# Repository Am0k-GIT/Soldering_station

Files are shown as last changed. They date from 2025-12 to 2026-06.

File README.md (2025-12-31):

<p align="center">
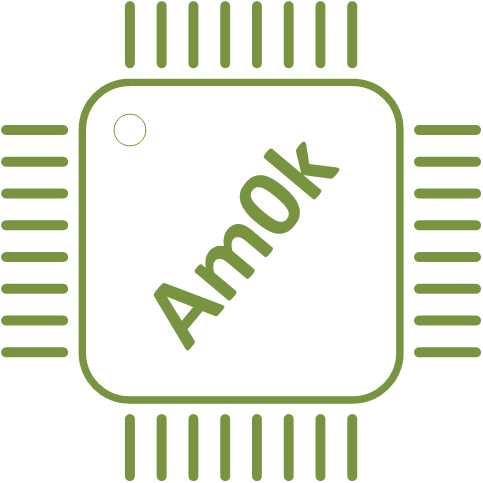
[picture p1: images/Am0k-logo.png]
  
</p>

<h1 align="center">Soldering Station</h1>

Паяльная станция основана на микроконтроллере от фирмы  STMicroelectronics STM32F401RCT6 и создана для одновременной работы с паяльником и термофеном. 
Она скомпонована на 2 печатных платах размером 100x70 мм. На первой (основной) печатной плате расположены: схема формирования вторичных напряжений питания, 
микроконтроллер и его обвязка, схема формирования входных сигналов АЦП на базе rail-to-rail ОУ, ключи управления нагрузкой (нагреватель паяльника, турбина фена, 
внешний вентилятор-дымоуловитель), кнопки управления, энкодеры, цветной LCD экран 1.77’’, разъемы для подключения. На второй печатной плате расположены элементы, 
касающиеся цепи питания 220В: реле включения блока питания паяльной станции, реле подключения ручки фена, симисторный драйвер управления нагревателем фена.

## Особенности.
<p align="center">
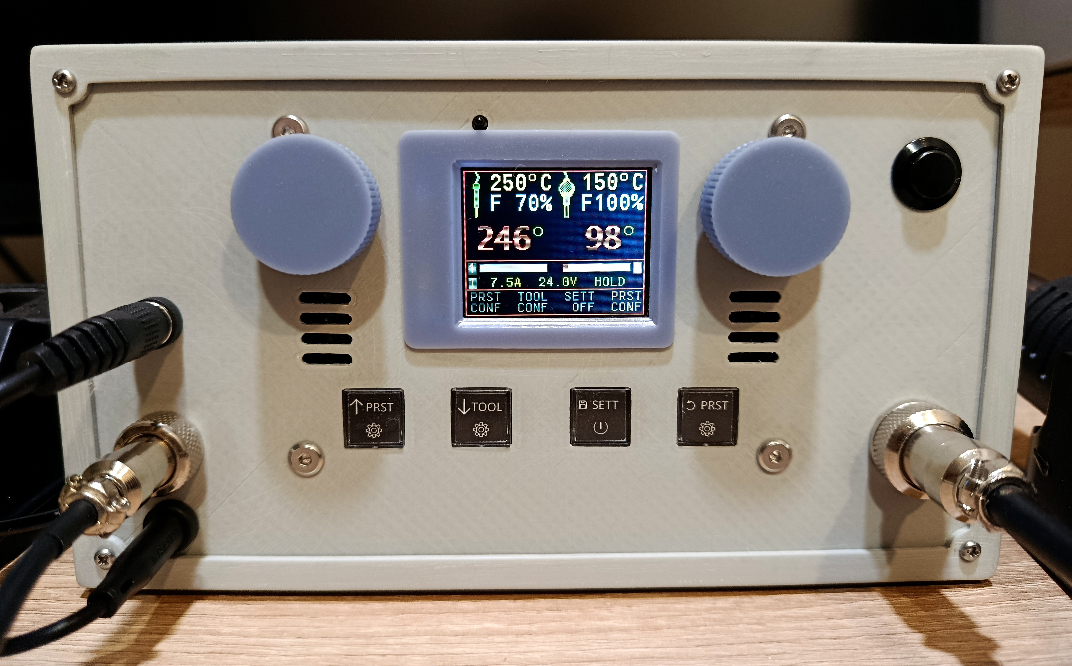
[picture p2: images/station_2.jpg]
  
</p>

Основные особенности:
- Напряжение питания 12-24 вольт от внешнего источника питания
- Одновременное подключение паяльника и термофена
- Возможность работы с жалами-картриджами с последовательным подключением нагревателя и термопары (как T12) или с общей землей нагревателя и термопары (как C245)
- PID управление мощностями нагревателей паяльника и термофена
- Широкий спектр доступных настроек для тюнинга станции под свои нужды

## BOM и производство.

Оригинальные печатные платы были произведены PCBWave. Для самостоятельного изготовления или заказа вы можете воспользоваться
GERBER-файлами и BOM-листом, приложенными в репозитории.

## Обратная связь.

Буду рад любой обратной связи относительно этого проекта, а так же отвечу на вопросы.
Почтовый адрес `b1gb0ss@mail.ru`.
Так же буду крайне благодарен в случае помощи с качественным переводом информации, размещенной в данном репозитории.

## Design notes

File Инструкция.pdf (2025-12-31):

## двухканальная паяльная станция от Am0k

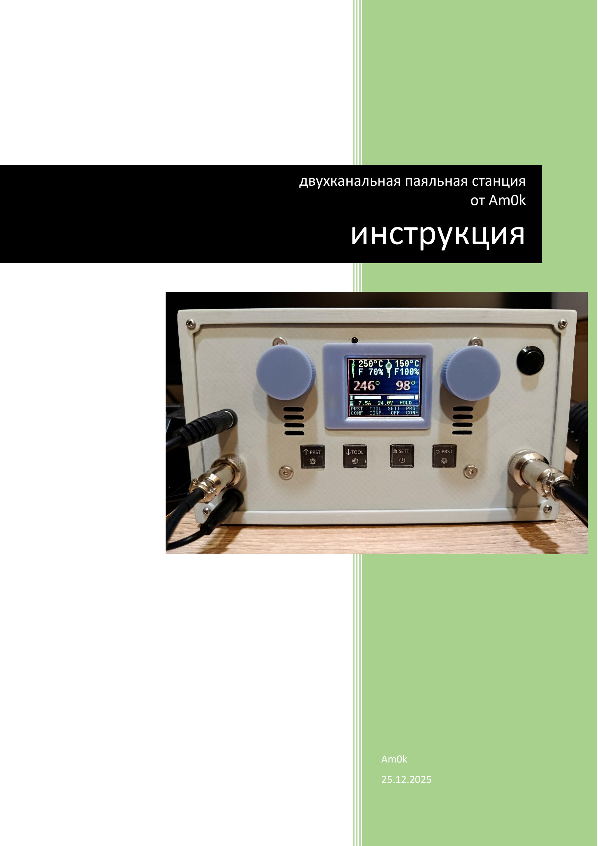
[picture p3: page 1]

Am0k

25.12.2025

# инструкция

## Оглавление

Общие технические характеристики.

Паяльная станция Helga основана на микроконтроллере от фирмы STMicroelectronics STM32F401RCT6 и создана для одновременной работы с паяльником и термофеном. Она скомпонована на 2 печатных платах размером 100x70 мм. На первой (основной) печатной плате расположены: схема формирования вторичных напряжений питания, микроконтроллер и его обвязка, схема формирования входных сигналов АЦП на базе rail-to-rail ОУ, ключи управления нагрузкой (нагреватель паяльника, турбина фена, внешний вентилятор-дымоуловитель), кнопки управления, энкодеры, цветной LCD экран 1.77’’, разъемы для подключения. На второй печатной плате расположены элементы, касающиеся цепи питания 220В: реле включения блока питания паяльной станции, реле подключения ручки фена, симисторный драйвер управления нагревателем фена.

Основные особенности:

- Напряжение питания 12-24 вольт от внешнего источника питания
- Одновременное подключение паяльника и термофена
- Возможность работы с жалами-картриджами с последовательным подключением нагревателя и термопары (как T12) или с общей землей нагревателя и термопары (как C245)
- PID управление мощностями нагревателей паяльника и термофена
- Широкий спектр доступных настроек для тюнинга станции под свои нужды

Подключение станции.

Для подключения станции потребуется блок питания напряжением 12-24 вольта, обеспечивающий мощность для выбранного типа жал, а также дополнительные 100 мА на нужды станции и ток, необходимый для внутреннего кулера обдува, турбины термофена, вентилятора-дымоуловителя. По умолчанию в станции установлен предохранитель 10А типоразмера 1808, который может быть заменен при необходимости.

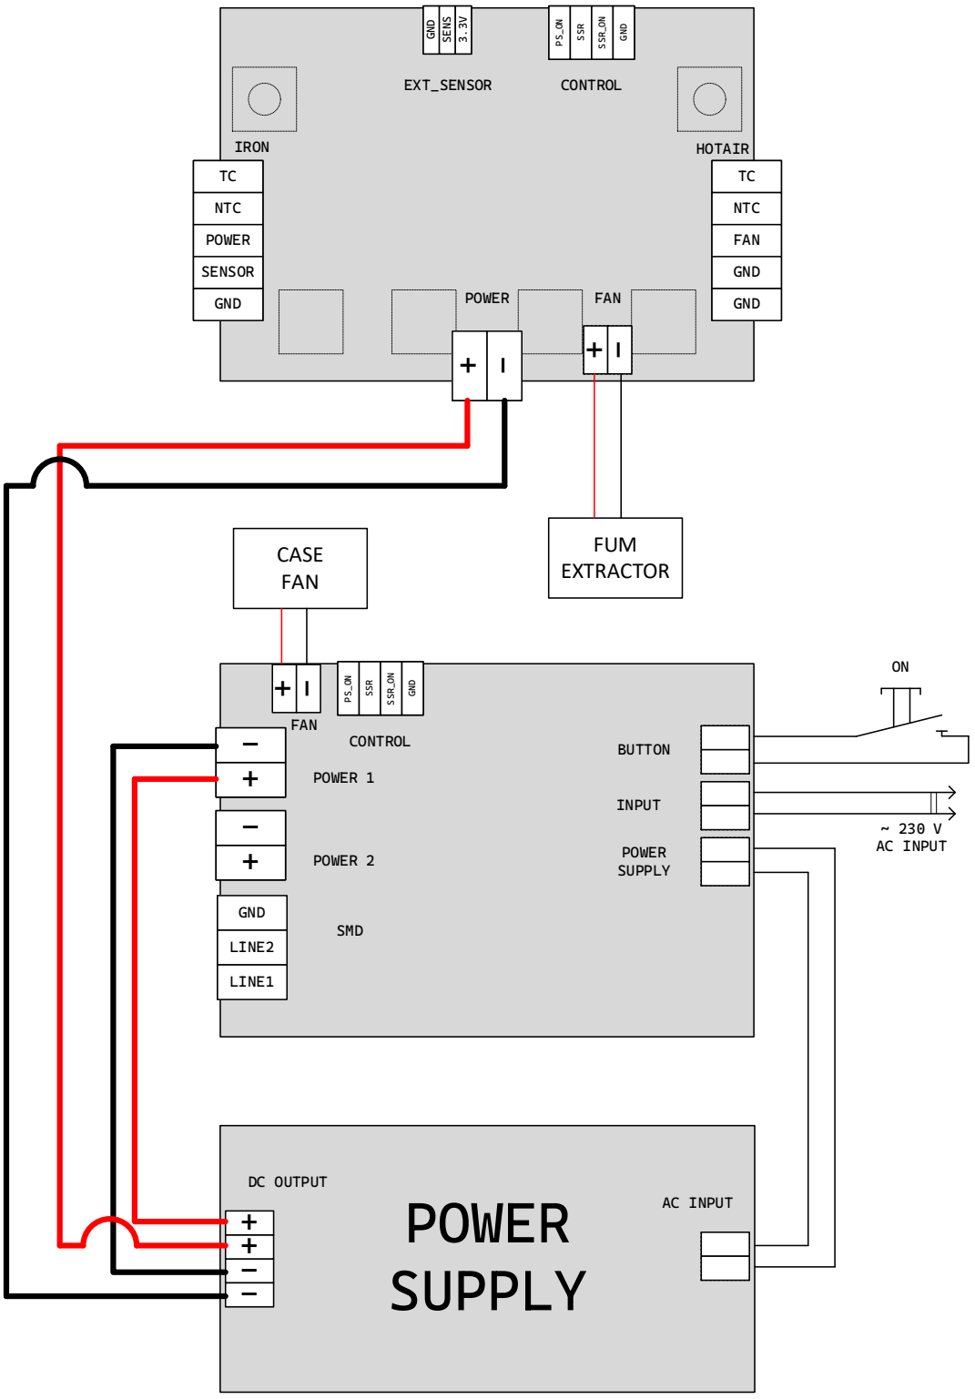
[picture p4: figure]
NTC; POWER; SENSOR; GND; FAN; - GND SENS 3.3V PS_ON SSR SSR_ON GND; EXT_SENSOR; CONTROL; IRON; HOTAIR PS_ON; SSR; SSR_ON; BUTTON; POWER 1; POWER 2; LINE2; LINE1; SMD; INPUT; POWER SUPPLY; POWER SUPPLY ⁻ -; AC INPUT; DC OUTPUT; FUM EXTRACTOR; CASE FAN; ~ 230 V AC INPUT

При отсутствии возможности подключения к блоку питания одновременно двух потребителей, на дополнительной плате предусмотрен разъем POWER 2, по сути являющийся дублирующим для POWER 1. В таком случае к блоку питания подключается только дополнительная плата, а основная подключается к разъему POWER 2.

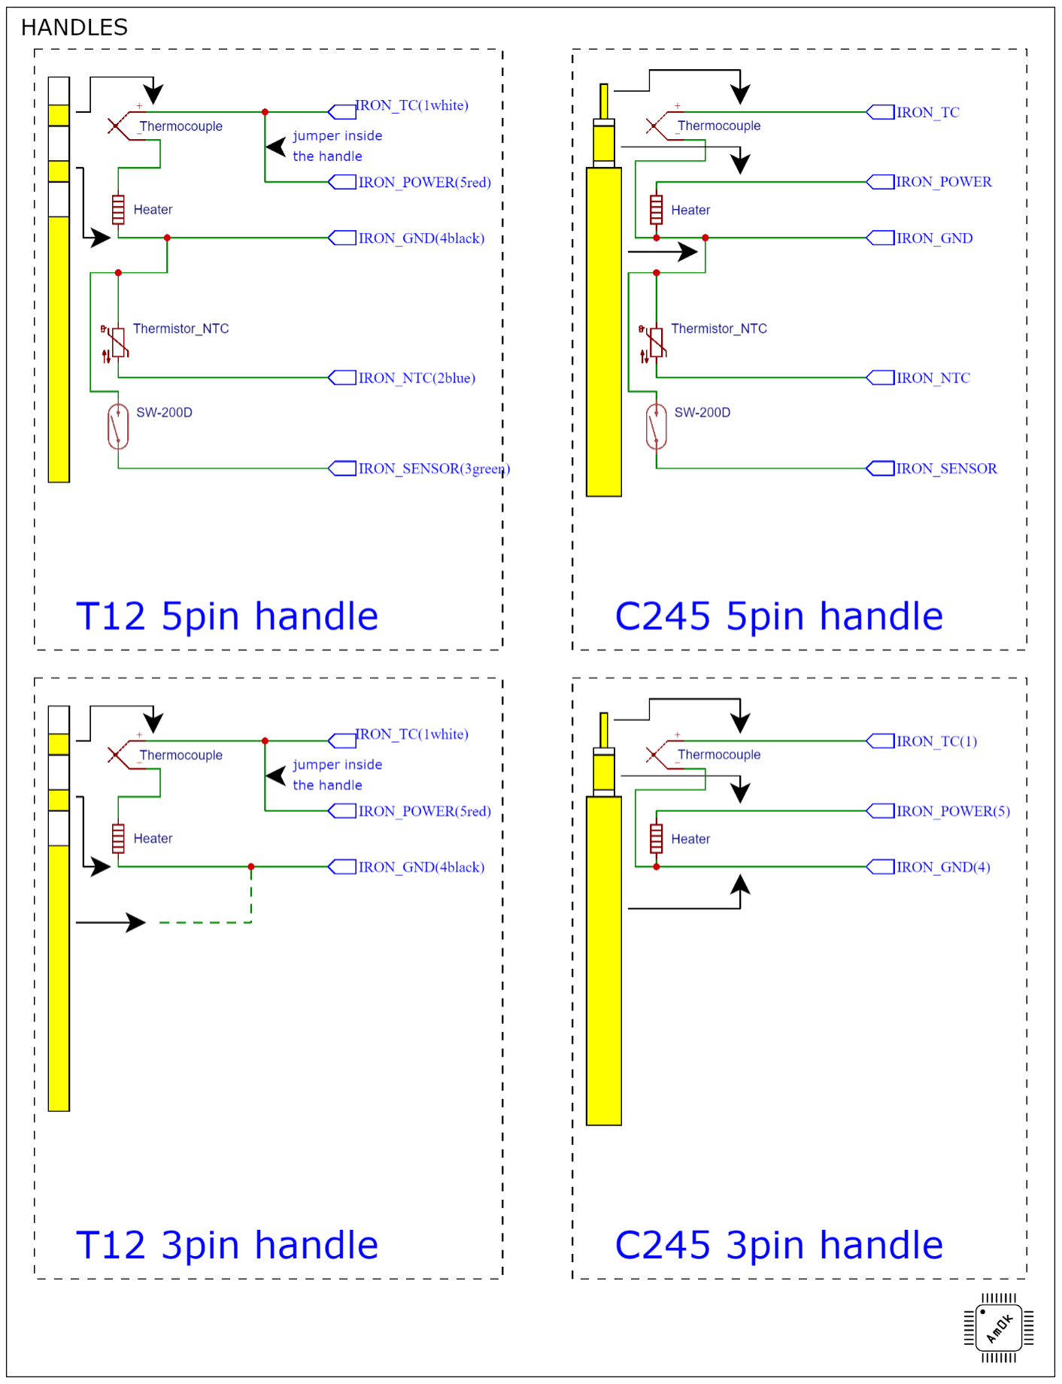
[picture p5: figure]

Рукоятки паяльника могут быть подключены по 3-ех, 4-ех или 5-ти проводной схеме, в зависимости от наличия внутреннего NTC резистора в рукоятке и датчика вибрации.

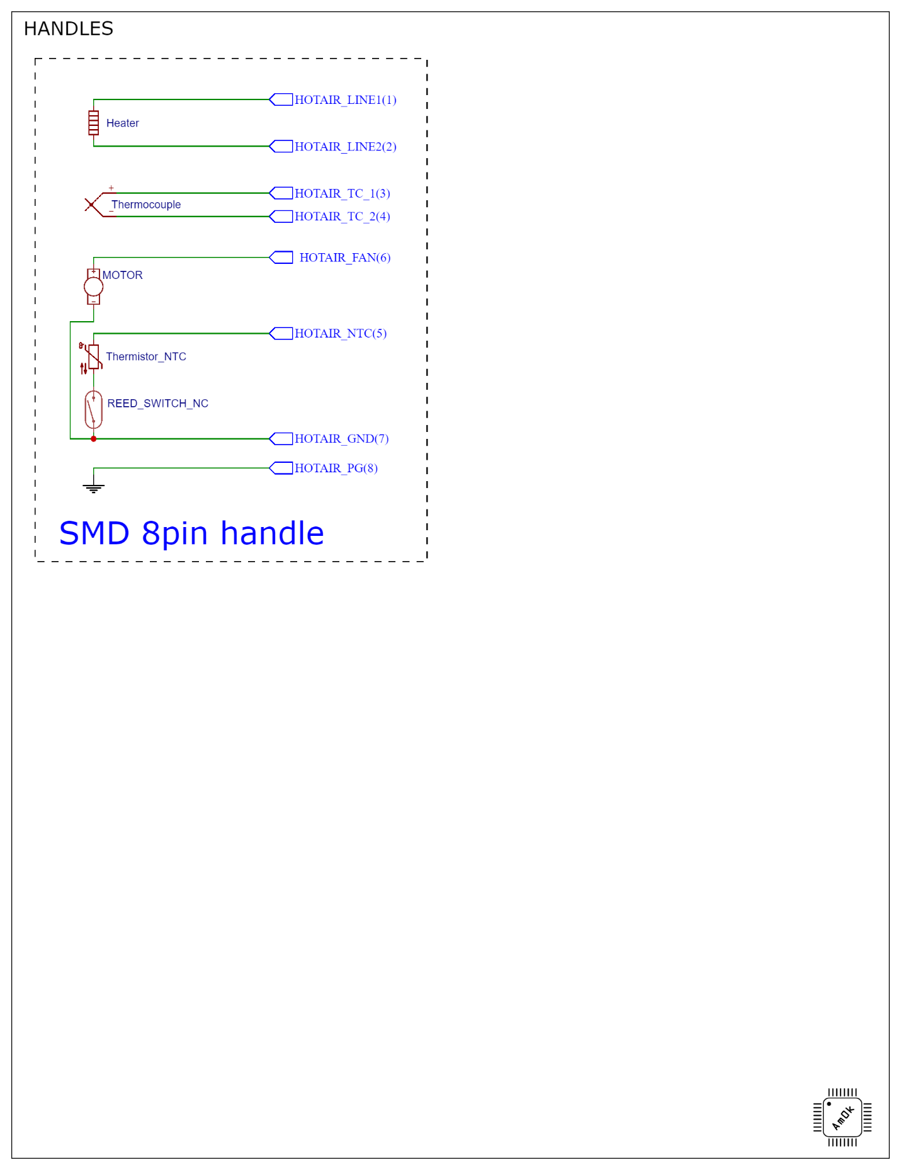
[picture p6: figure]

Рукоятка термофена подключается по 8 проводной схеме. Сигналы LINE1, LINE2 и PG берутся с разъема дополнительной печатной платы. Отрицательный вывод термопары подключается на один из выводов GND разъема HOTAIR основной печатной платы.

Так же между печатными платами устанавливается шлейф для управления дополнительной печатной платой (разъемы CONTROL, одноименные сигналы соединяются друг с другом).

Подключение подставки с детектированием наличия инструмента.

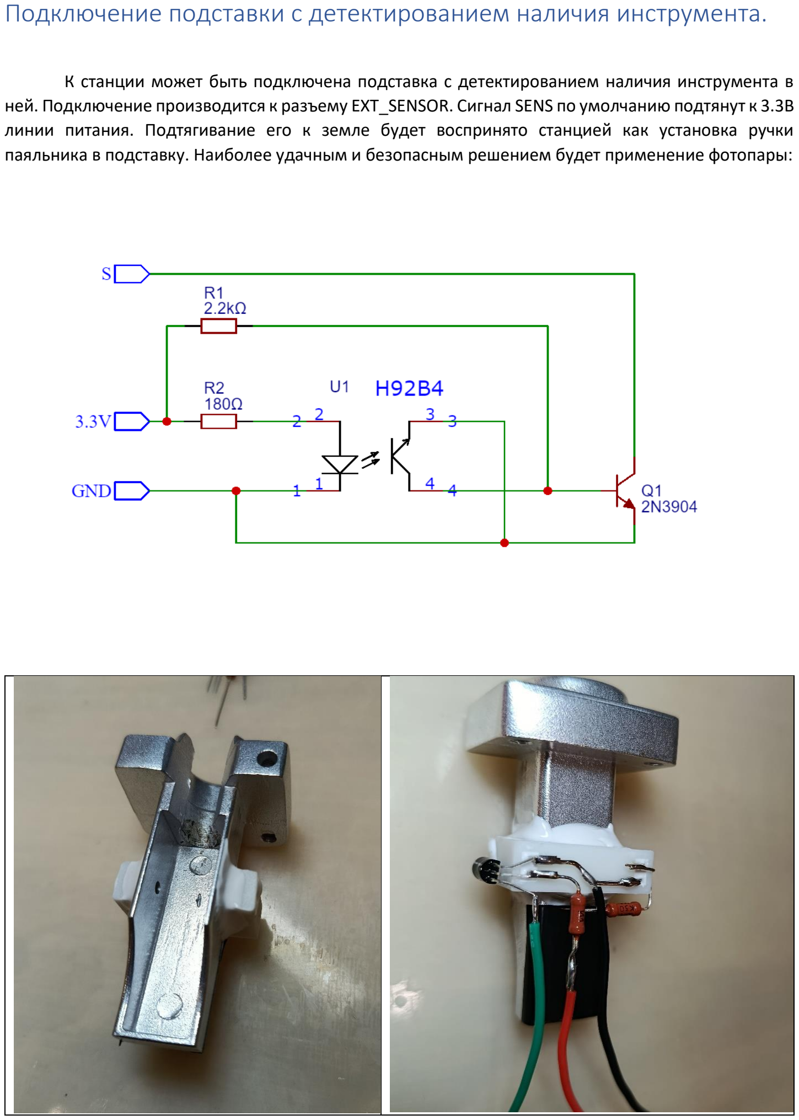
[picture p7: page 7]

К станции может быть подключена подставка с детектированием наличия инструмента в ней. Подключение производится к разъему EXT_SENSOR. Сигнал SENS по умолчанию подтянут к 3.3В линии питания. Подтягивание его к земле будет воспринято станцией как установка ручки паяльника в подставку. Наиболее удачным и безопасным решением будет применение фотопары:

Алгоритм работы.

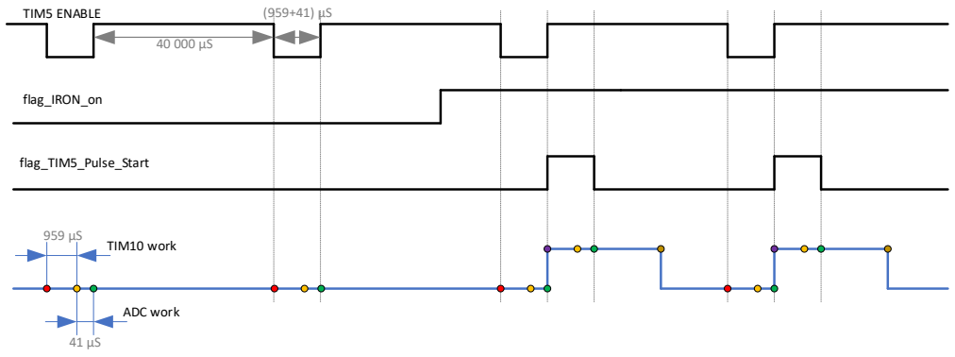
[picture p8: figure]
TIM5 ENABLE; flag_IRON_on; TIM10 work; ADC work; flag_TIM5_Pulse_Start

Алгоритм работы станции рассчитан на работу как с жалами, имеющими последовательное соединение термопары и нагревателя, так и с трех-контактными жалами с общим минусом для термопары и нагревателя. Частота ШИМ сигнала составляет 25 Гц. По завершению каждого периода ШИМ осуществляется задержка длительностью 959 мкС., после которой начинает свою работу АЦП. По завершению работы АЦП вновь следует запуск импульса ШИМ и одновременно сигнала задержки для нового измерения, на этот раз уже во время непосредственного нагрева (в случае его включения) измеряется ток, текущий через нагреватель жала. При завершении положительного импульса ШИМ, если АЦП еще не завершил работу, устанавливается флаг, указывающий на слишком короткий импульс для достоверного измерения тока. Подробные блок-схемы работы ПО в части, касающейся работы АЦП и ШИМ, приведены в справочной информации.

Меню и управление станцией.

Меню загрузки.

# RST EXIT

# LOADING SETTINGS:

IRON SETT. | - OK
HOTAIR SETT. | - OK
HW SETT. | - OK
IRON TOOLS | - OK
HOTAIR TOOLS | - OK
IRON PRES. | - OK
HOTAIR PRES. | - OK
VERSION: | 251103

При включении станции на экране появится меню загрузки. В нем будут отображены параметры успешности загрузки всех сохраняемых в EEPROM настроек. В случае успешной загрузки напротив блока настроек появится надпись OK, в случае, если настроек нет (они ни разу не были сохранены в EEPROM), будут загружены настройки по-умолчанию для данного блока, и появится надпись FAIL. Внизу экрана будет отображена версия прошивки. Доступные кнопки: RST для полной очистки EEPROM и установки настроек по-умолчанию, EXIT для мгновенного выхода из меню без ожидания автоматической загрузки следующего меню.

Основное меню.
250°C | 150°C
F100% | F 80%
PRST | TOOL | SETT | PRST
CONF | CONF | OFF | CONF
1 | | 1
2 | 8.2A 24.1V HOLD
249° | 138°

Находясь в основном меню, экран разделен на несколько зон в соответствии с их назначением.

В верхней левой части экрана отображаются параметры, касающиеся паяльника: установленная температура, установленная скорость работы вентилятора-дымоуловителя, реальная температура. Отображаемое значение реальной температуры меняет цвет в зависимости от того, включен ли нагрев (красный при включении, зеленый при отключении нагрева).

В верхней правой части экрана отображаются параметры, касающиеся термофена: установленная температура, установленная скорость работы турбины, реальная температура. Отображаемое значение реальной температуры меняет цвет в зависимости от того, включен ли нагрев (красный при включении, зеленый при отключении нагрева).

В средней части экрана отображаются: индикатор подаваемой на нагреватели паяльника (слева) и термофена (справа) мощности. Также отображаются номер установленного пресета и установленного инструмента для паяльника слева, и установленного пресета для термофена справа. Ниже находится справочная информация: потребляемый нагревателем жала паяльника ток или его состояние (HOLD при удержании температуры сна, ----- при отключении инструмента из за неиспользования), напряжение блока питания, состояние термофена.

В нижней части расположена подсказка по управлению станции с помощью кнопок, где верхний ряд – короткое нажатие соответствующей кнопки, нижний ряд – длинное нажатие, список приведен слева направо:

PRST – переключение пресетов для паяльника

CONF – меню настройки пресетов паяльника

TOOL – переключение предварительно откалиброванных инструментов (жал) для паяльника

CONF – меню настройки инструментов

SETT – меню настроек станции

OFF – отключение станции

PRST – переключение пресетов для термофена

CONF – меню настройки пресетов термофена

Левый энкодер меняет параметры, касающиеся пальника: установленную температуру и обдув вентилятора-дымоуловителя. Короткое нажатие энкодера переключается между параметрами (температура или нагрев), длинное включает и выключает нагрев.

Правый энкодер меняет параметры, касающиеся термофена: установленную температуру и скорость турбины. Короткое нажатие энкодера переключается между параметрами (температура или нагрев), длинное включает и выключает нагрев.

Меню настроек.

В меню настроек вы можете настроить основные параметры станции. Кнопки BACK и NEXT перемещают курсор > выбора параметра. Кнопка SAVE сохраняет блок настроек в EEPROM, кнопка EXIT закрывает меню и переводит экран в режим отображения основного меню.

Вращая правый энкодер при установленном на название страницы настроек курсоре вы можете переключать страницы настроек между HOTAIR SETTINGS, IRON SETTINGS, HW SETTINGS. Если же курсор установлен на одном из пунктов настроек, то его вращение приведет к изменению значения.

BACK | NEXT | SAVE | EXIT

# > HOTAIR SETTINGS:

MIN TEMP: | 120°C
MAX TEMP: | 450°C
STEP TEMP: | 10°C
MIN FLOW: | 40 %
MAX FLOW: | 100 %
STEP FLOW: | 10 %
TOOL NTC: | MF52
TOOL SENSOR: | Y
SLEEP TIMER: | 60 S

Доступные в меню HOTAIR SETTINGS настройки:

MIN TEMP – минимальная температура, которую можно установить

MAX TEMP – максимальная температура, которую можно установить

STEP TEMP – шаг изменения температуры

MIN FLOW – минимальный поток воздуха, который можно установить

MAX FLOW - максимальный поток воздуха, который можно установить

STEP FLOW – шаг изменения потока воздуха

TOOL NTC – выбор NTC, установленного в рукоятке. N означает отсутствие NTC, в таком случае для подсчета температуры холодного спая будет использован NTC, установленный в станции

TOOL SENSOR – установлен ли в ручке сенсор

SLEEP TIMER – время, через которое термофен перейдет в режим HOLD, будучи установленным в подставку

BACK | NEXT | SAVE | EXIT
> | IRON SETTINGS:
MIN TEMP: | 120°C
MAX TEMP: | 450°C
STEP TEMP: | 10°C
MIN FLOW: | 40 %
MAX FLOW: | 100 %
STEP FLOW: | 10 %
TOOL NTC: | N
TOOL SENSOR: | N
SLEEP TIMER: | 60 S

Настройки подменю IRON SETTINGS аналогичны. Если TOOL SENSOR установлен в N (в ручке нет сенсора), то будет использован внешний сенсор (активная подставка).

BACK | NEXT | SAVE | EXIT
> | HW SETTINGS:
INT NTC: | MF52
0 CURRENT: | 2290
K CURRENT: | 100
K VOLTAGE: | 100
K INT NTC: | 100
K IRON NTC: | 100
K HOTAIR NTC: | 100
TIME OFF: | 1200 S
OVERCURRENT: | 8 A

Страница настроек HW SETTINGS содержит следующие пункты:

INT NTC – выбор встроенного в плату станции NTC

0 CURRENT – показания АЦП для нулевого тока ACS712-20A

K CURRENT – коэффициент коррекции для измерения тока жала

K VOLTAGE – коэффициент коррекции для измерения напряжения блока питания

K INT NTC – коэффициент коррекции для измерения температуры встроенным NTC

K IRON NTC – коэффициент коррекции для измерения температуры NTC, встроенным в рукоятку паяльника

K HOTAIR NTC – коэффициент коррекции для измерения температуры NTC, встроенным в рукоятку фена

TIME OFF – время перехода инструмента из режима HOLD в режим OFF

OVERCURRENT – максимальное значение тока жала паяльника. При превышении нагрев прекращается.

Меню настройки пресетов паяльника.

BACK | NEXT | SAVE | EXIT

# IRON PRESETS:

#1 | >T:250°C | F: 70%

#2 | T:270°C | F: 80%

#3 | T:320°C | F:100%

В меню настройки пресетов паяльника можно сохранить 3 различных пресета. Кнопками BACK и NEXT осуществляется навигация по меню, вращение правого энкодера меняет значение выбранного параметра.

Меню настройки пресетов термофена.

BACK | NEXT | SAVE | EXIT

# HOTAIR PRESETS:

#1 | >T:150°C | F:100%

#2 | T:320°C | F: 60%

#3 | T:350°C | F:100%

В меню настройки пресетов паяльника можно сохранить 3 различных пресета. Кнопками BACK и NEXT осуществляется навигация по меню, вращение правого энкодера меняет значение выбранного параметра.

Меню настройки инструментов.

BACK | NEXT | SAVE | EXIT

# > TOOL: IRON#1

P: | 200
I: | 100
D: | 200
ADC (Δ 0°C): | 90
ADC (Δ120°C): | 600
ADC (Δ240°C): | 1330
ADC (Δ360°C): | 2040
026°C Δ120°C | 612

В меню настройки инструментов навигация осуществляется стандартным способом. При выборе заголовка меню вращение правого энкодера меняется инструмент (термофен и 5 вариантов жал паяльника). Кнопки BACK и NEXT перемещают курсор выбора пункта меню вверх и вниз соответственно. Доступные пункты меню:

P – коэффициент P для PID регулятора выбранного инструмента

I - коэффициент I для PID регулятора выбранного инструмента

D - коэффициент D для PID регулятора выбранного инструмента

ADC (Δ 0°C) - ADC (Δ360°C) – показания АЦП при заданной дельте темпретаруры термопары и холодного спая.

Ниже расположены значения: температура холодного спая (зеленым), дельта температуры термопары и холодного спая (красным) и текущие показания АЦП (желтым). Под ними расположена шкала коррекции. Подробнее о функциональном назначении данной страницы настроек рассказано в главе “Калибровка инструментов”.

Калибровка инструментов.

Для калибровки инструментов перейдите в меню настройки инструментов и выберите в заголовке требуемый инструмент.

Для базовой настройки PID регулятора сначала установите коэффициенты P, I, D в ноль.

P – пропорциональная составляющая воздействия вашего регулятора. Ее значение пропорционально отклонению регулируемой величины (температуры в нашем случае) от заданного значения. Сама по себе пропорциональная составляющая не способна привести к стабилизации системы. По мере увеличения составляющей будет происходить перерегулирование в виде появление вначале незатухающих колебаний, а затем и вовсе колебаний с нарастающей амплитудой. Идеально подобранный коэффициент P позволит стабилизироваться системе в состоянии небольшого недогрева с незначительными колебаниями. Так, при выставленной температуре в 250°С, постепенным увеличением коэффициента P будет необходимо добиться выхода системы на температуру 245-249°С с незначительными колебаниями (не более 5°С). Это наиболее важный этап настройки регулятора, и он потребует нескольких итераций. Просто увеличивайте коэффициент P, возвращайтесь в главное меню и следите за изменениями в стабильности системы.

I - интегрирующая составляющая, она пропорциональна интегралу по времени от отклонения регулируемой величины. Ее основное значение – компенсация статической ошибки в виде небольшого недогрева, полученного при настройке коэффициента P. Необходимо столь же плавно увеличивать ее до тех пор, пока система не начнет стабилизироваться вокруг установленной температуры с незначительными (1-2°С) колебаниями. Слишком малое значение коэффициента I не позволит системе достигнуть заданной температуры. Однако чрезмерное значение коэффициента приведет к увеличению инертности системы, что подходит для термофена, но не для жала паяльника.

D - дифференцирующая составляющая, она пропорциональна темпу изменения отклонения регулируемой величины и предназначена для противодействия отклонениям от целевого значения. Именно эта составляющая будет “сопротивляться” резкому изменению температуры. Однако, это будет выражаться не только в значительном увеличении подаваемой мощности во время просадки температуры при касании крупного медного полигона жалом паяльника, но и при резком возвращении температуры в момент прекращения значительного отбора тепла. Для точного подбора этого коэффициента потребуется практическое применение паяльника с возможно большим отбором тепла. Увеличивайте коэффициент от нуля до значения, при котором система не уходит в перерегулирование и не начинаются выбросы температуры. Для термофена этот коэффициент имеет наименьшее практическое значение.

Несмотря на то, что регулировка коэффициентов PID долгий и порой неоднозначный по выводам процесс, именно тонкий подбор коэффициентов позволит раскрыть полный потенциал инструмента.

Тарирование термопары инструмента необходимо производить после калибровки PID и получения на выходе регулятора стабильной температуры.

На полностью холодном инструменте установите ADC (Δ 0°C) равное текущим показаниям АЦП.

При переходе на пункт ADC (Δ120°C) начнется нагрев инструмента до температуры (Tntc + 120)°C. Добейтесь стабилизации температуры и начните контроль реальных значений температуры внешним измерительным прибором. Используйте легкоплавкие припои (сплав Вуда, сплав Розе) для калибровки по крайней мере этой точки тарирования. Вращая левый энкодер, вы можете увеличивать и уменьшать установленную температуру, нижняя цветная шкала соответствует вносимой вами поправке. Необходимо добиться стабильных показаний реальной температуры, соответствующих (Tntc + 120)°C, после чего вращением правого энкодера ввести установившееся значение АЦП. Если достигнуты границы возможной поправки, можно сохранить достигнутый результат, выйти из меню, и затем вернуться в него вновь. Это вновь установит поправку в 0 (середина шкалы), однако установленная температура будет уже больше соответствовать реальной за счет обновленного значения АЦП.

Повторите предыдущий пункт для пунктов ADC (Δ240°C) и ADC (Δ360°C).

При сохранении результатов, в таблицу калибровки в EEPROM так же будет записано автоматически посчитанное значение максимально измеряемой температуры при 4000 отсчетов АЦП. Этот результат будет получен аппроксимацией участка ADC (Δ240°C) - ADC (Δ360°C).

Справочная информация.

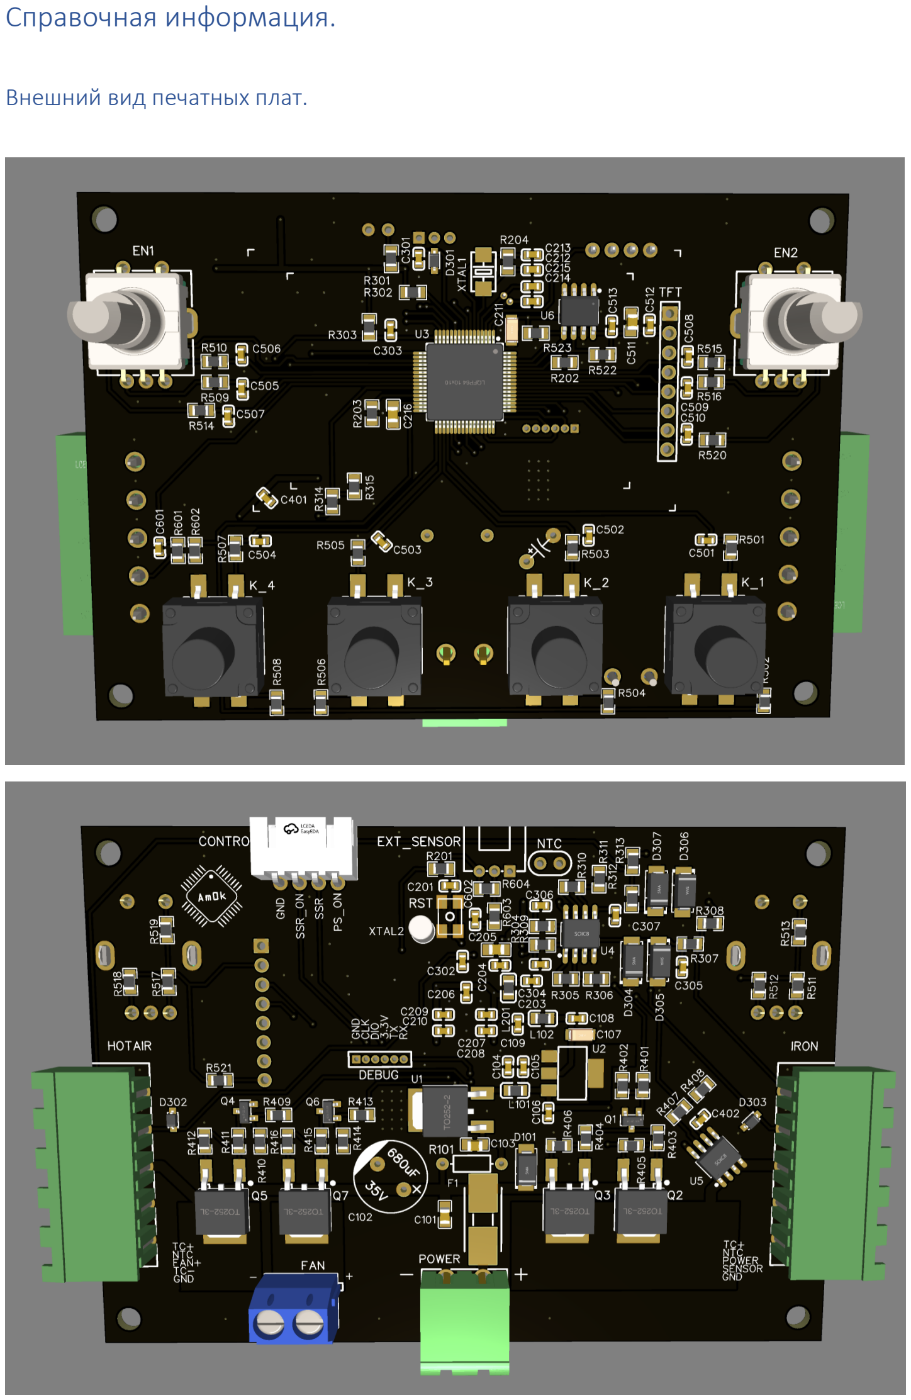
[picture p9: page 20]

Внешний вид печатных плат.

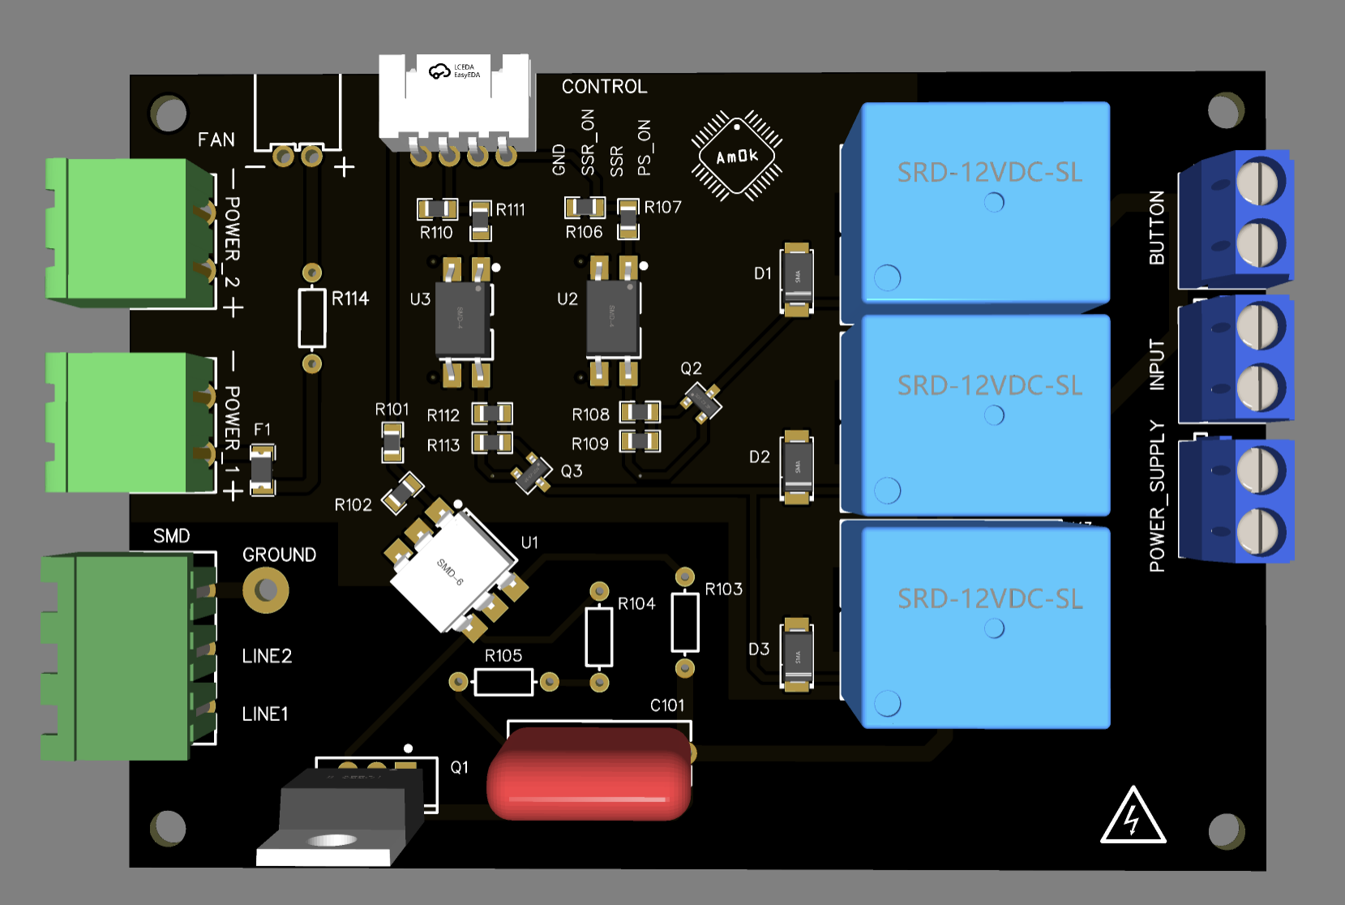
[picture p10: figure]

Размеры.

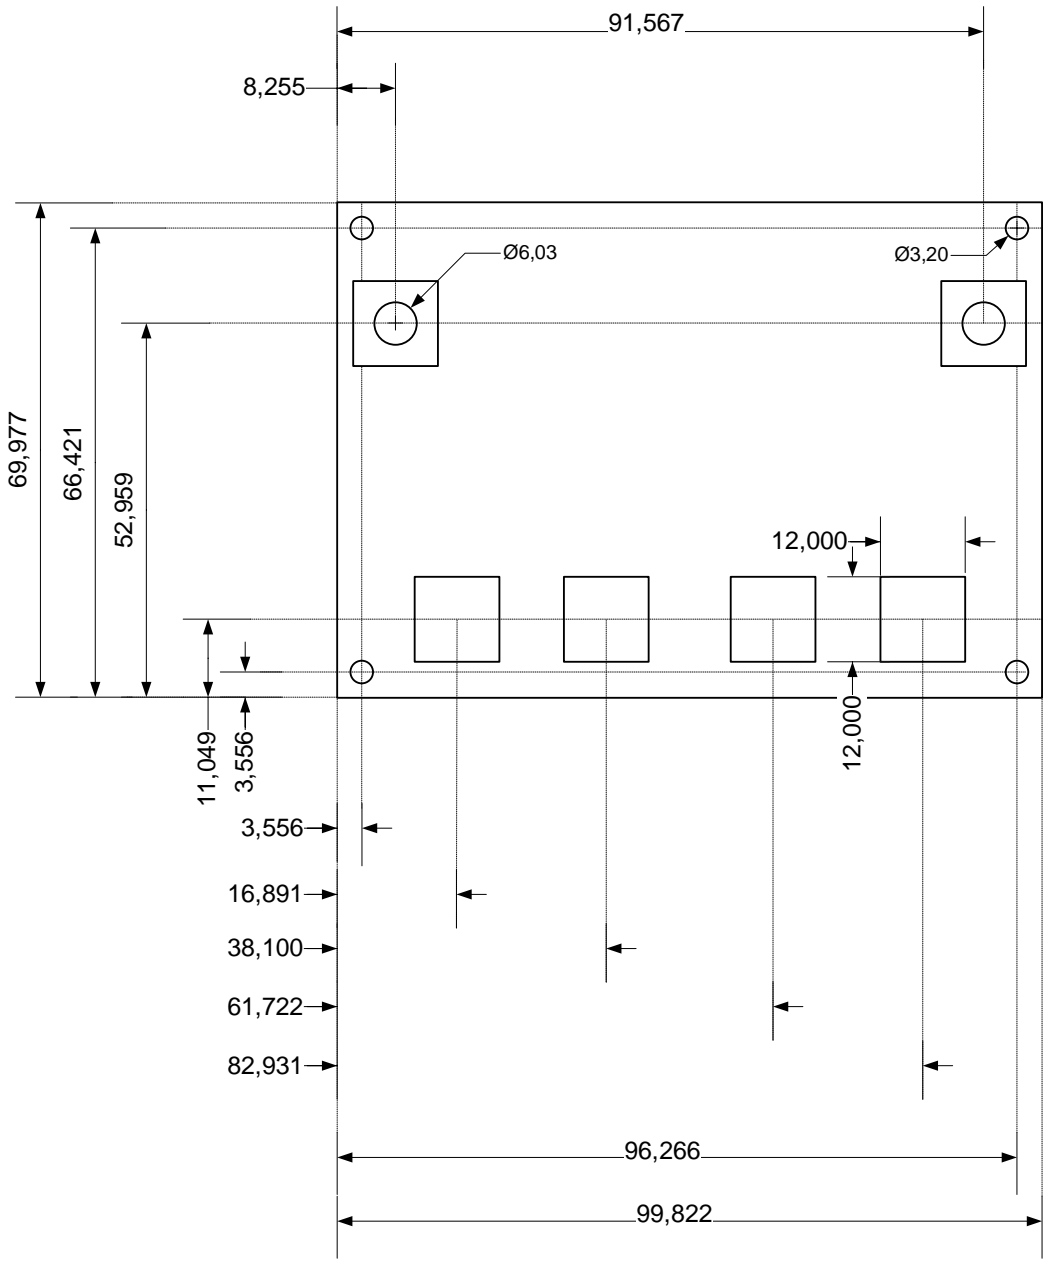
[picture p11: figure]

Алгоритм обработки нажатия кнопок.

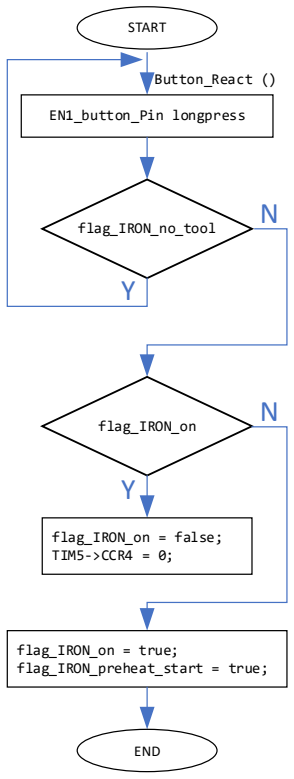
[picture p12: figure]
START; EN1_button_Pin longpress; flag_IRON_no_tool; flag_IRON_on; flag_IRON_on = false; TIM5->CCR4 = 0;; flag_IRON_on = true; flag_IRON_preheat_start = true;; END; Button_React ()

Алгоритм обработки завершения импульса ШИМ нагрева.

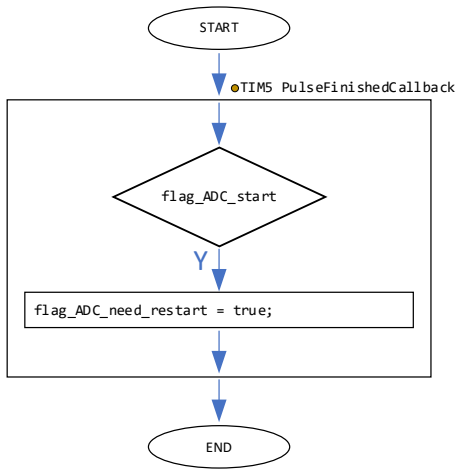
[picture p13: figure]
START; TIM5 PulseFinishedCallback; END; flag_ADC_start; flag_ADC_need_restart = true;

Алгоритм работы АЦП и ШИМ.

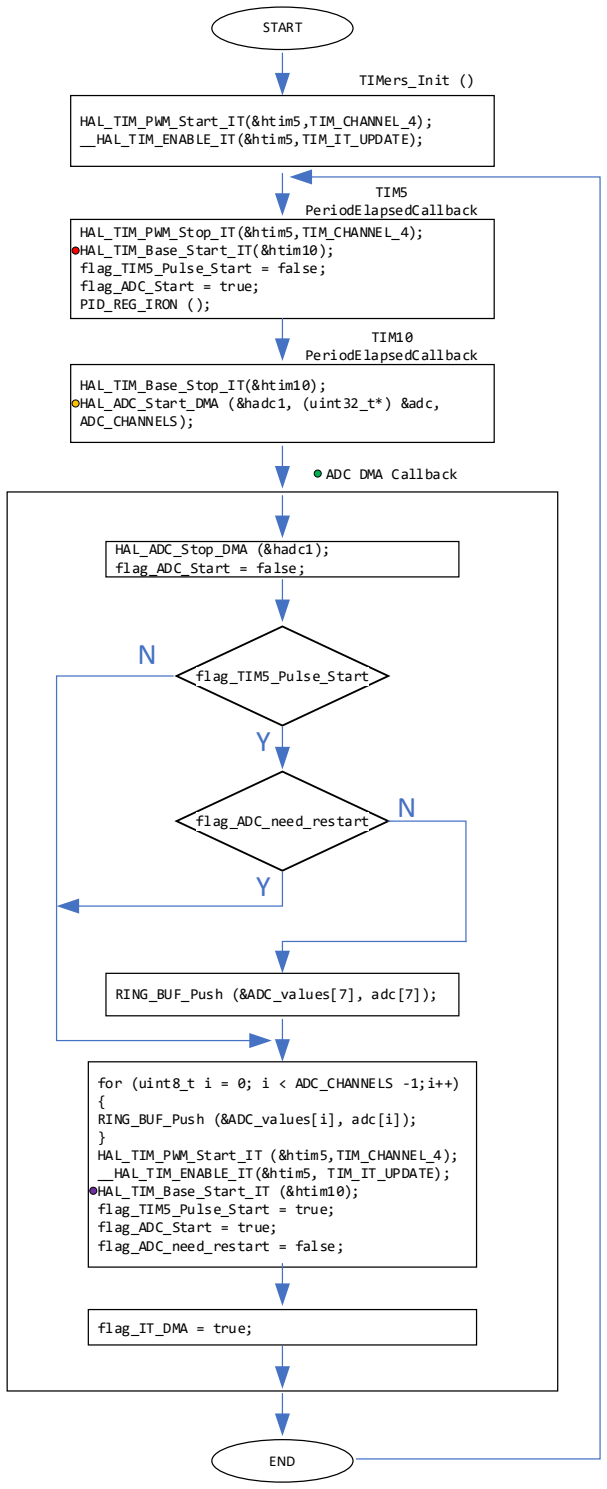
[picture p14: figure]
START; HAL_TIM_PWM_Start_IT(&htim5,TIM_CHANNEL_4); __HAL_TIM_ENABLE_IT(&htim5,TIM_IT_UPDATE);; TIMers_Init (); HAL_TIM_PWM_Stop_IT(&htim5,TIM_CHANNEL_4); HAL_TIM_Base_Start_IT(&htim10); flag_TIM5_Pulse_Start = false; flag_ADC_Start = true; PID_REG_IRON ();; TIM5 PeriodElapsedCallback; TIM10 PeriodElapsedCallback; HAL_TIM_Base_Stop_IT(&htim10); HAL_ADC_Start_DMA (&hadc1, (uint32_t*) &adc, ADC_CHANNELS);; ADC DMA Callback; HAL_ADC_Stop_DMA (&hadc1); flag_ADC_Start = false;; flag_TIM5_Pulse_Start; RING_BUF_Push (&ADC_values[7], adc[7]);; { RING_BUF_Push (&ADC_values[i], adc[i])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

for (uint8_t i = 0; i < ADC_CHANNELS -1;i++)

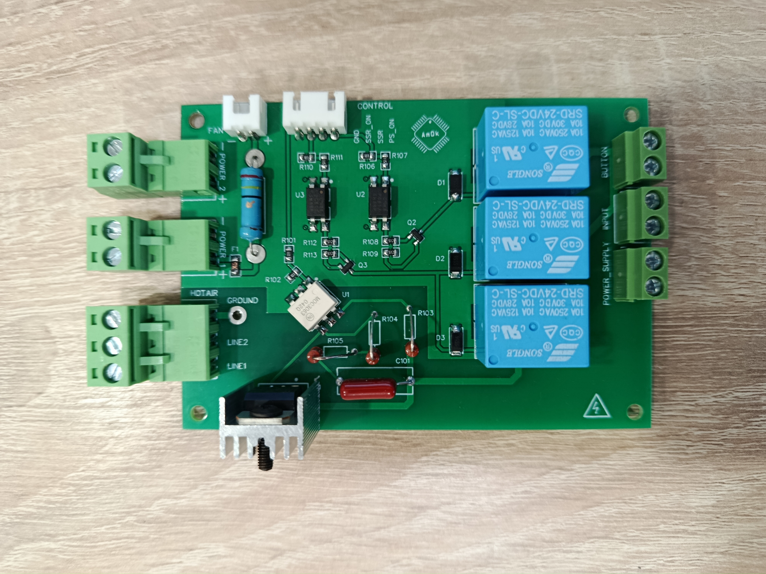
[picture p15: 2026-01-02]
images/PCB_3.jpg

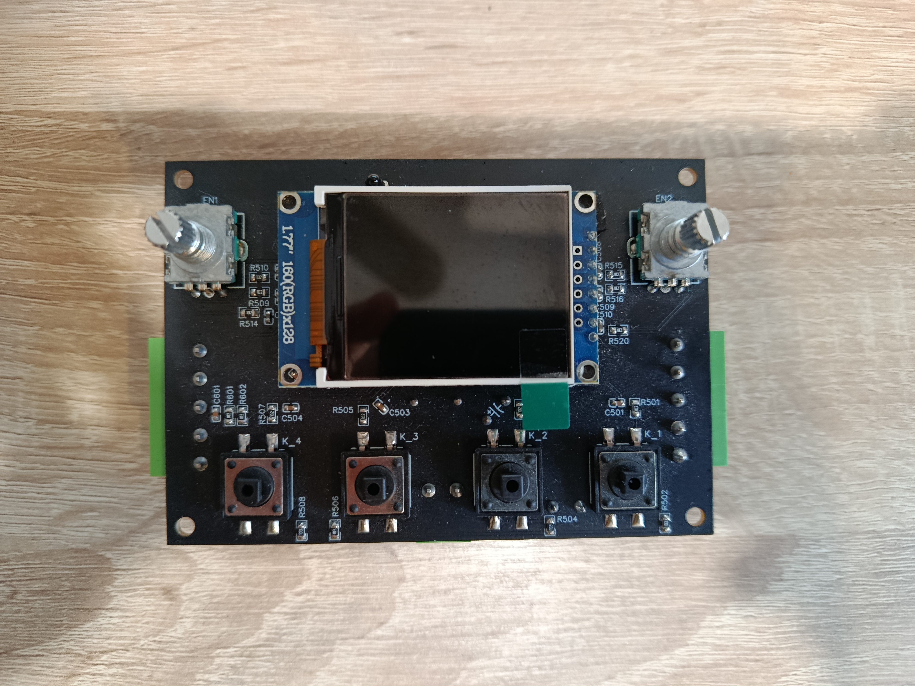
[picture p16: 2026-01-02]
images/PCB_2.jpg

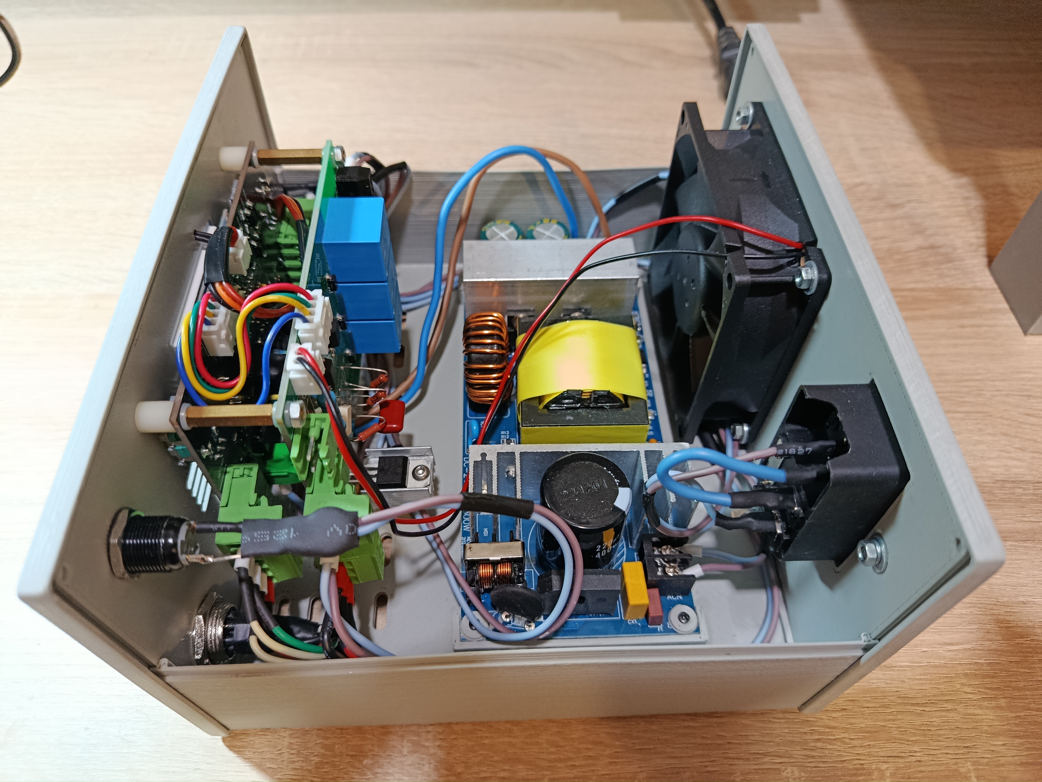
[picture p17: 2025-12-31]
images/station_3.jpg

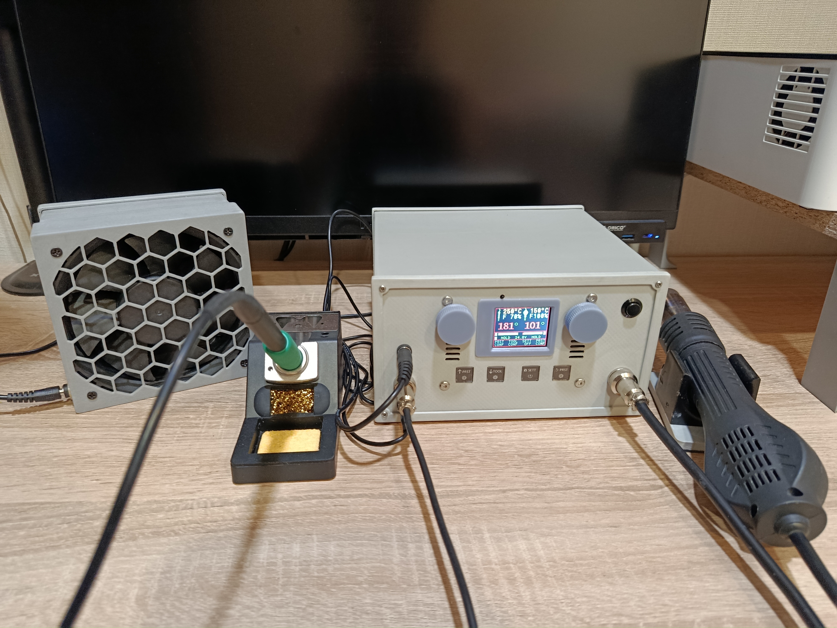
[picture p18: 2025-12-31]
images/station_1.jpg

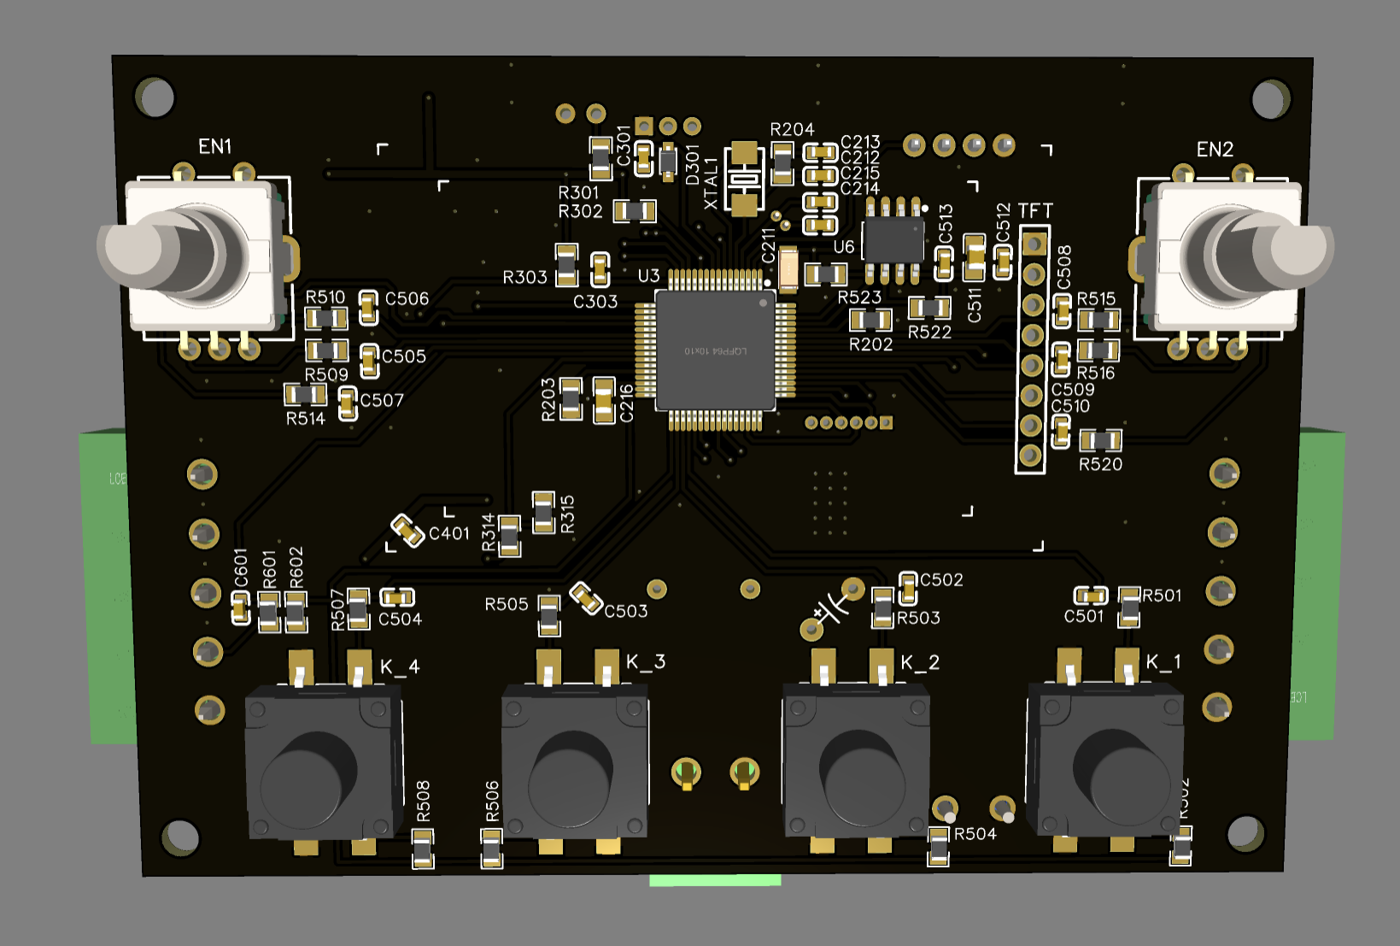
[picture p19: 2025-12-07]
images/preview_PCB.png

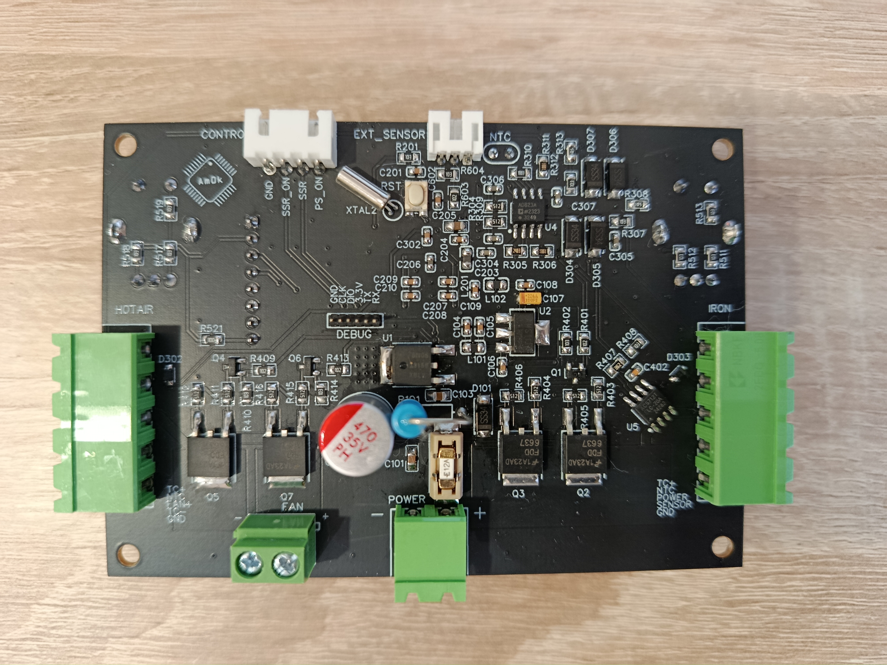
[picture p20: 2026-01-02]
images/PCB_1.jpg

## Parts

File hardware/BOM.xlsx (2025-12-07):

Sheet: BOM_Soldering_station_p1
 |  |  |  | Кол-во | Цена | Итоговая цена
Capacitors
 | 15pF | C212,C213,C214,C215 | C0603 | 4 | 1 | 4
 | 1nF | C402 | C0603 | 1 | 1 | 1
 | 10nF | C206,C304,C306,C305,C307,C203,C505,C506,C507,C508,C509,C510 | C0603 | 12 | 1 | 12
 | 100nF | C302,C602,C207,C208,C209,C210,C201,C104,C105,C106,C108,C109,C204,C301,C303,C401,C501,C502,C503,C504,C512,C513,C601 | C0603 | 23 | 1 | 23
 | 0.1uF | C101 | C0805 | 1 | 1 | 1
 | 1uF | C103,C205,C511 | C0805 | 3 | 1 | 3
 | 4.7uF | C216 | C0805 | 1 | 1 | 1
 | 22uF/10V | C107,C211 | CASE-A | 2 | 18 | 36
 | 680uF/35V | C102 | TH capacitor W10.0 P5.0 D0.6 | 1 | 20 | 20
Resistors
 | 10Ω | R521 | R0805 | 1 | 1 | 1
 | 1kΩ | R409,R413,R603,R401,R315,R501,R503,R505,R507,R509,R510,R514,R515,R516,R520,R601 | R0805 | 16 | 1 | 16
 | 3.6kΩ | R407 | R0805 | 1 | 1 | 1
 | 5.1kΩ | R304,R309,R411,R412,R415,R416,R403,R404,R405,R406 | R0805 | 10 | 1 | 10
 | 10kΩ | R408,R410,R414,R604,R402,R517,R518,R519,R511,R512,R513,R201,R307,R312,R314,R502,R504,R506,R508,R522,R523,R602 | R0805 | 22 | 1 | 22
 | 100kΩ | R202,R203 | R0805 | 2 | 1 | 2
 | 1MΩ | R204 | R0805 | 1 | 1 | 1
 | 2MΩ | R308,R313 | R0805 | 2 | 1 | 2
 | 1kΩ* | R306,R311 | R0805 | 2 | 10 | 20
 | 4.7kΩ* | R301,R302,R303 | R0805 | 3 | 10 | 30
 | 240kΩ* | R305 | R0805 | 1 | 10 | 10
 | 100kΩ* | R310 | R0805 | 1 | 10 | 10
 | 22Ω | R101 | TH resistor 1W | 1 | 10 | 10
 | MF52AT 10k | NTC | NTC-MF52AT 100K | 1 | 10 | 10
Ferrite Beads
 | 10Ω/100MHz | L101,L102 | L0805 | 2 | 2 | 4
 | 100Ω/100MHz | L201 | L0805 | 1 | 2 | 2
Fuses
 | SMD 1808 | F1 | SMD FUSEHOLDER | 1 | 13 | 13
Oscillators
 | 8M | XTAL1 | X2-SMD-5.0X3.2X1.3MM | 1 | 50 | 50
 | 32.768K | XTAL2 | CRYSTAL-TH_BD3.0-P1.10-D0.4 | 1 | 10 | 10
Diodes
 | PESD3V3L1UA | D303,D302,D301 | SOD-323 | 3 | 5 | 15
 | SS34 | D304,D305,D306,D307,D101 | SMA | 5 | 8 | 40
Transistors
 | BC817-40 | Q4,Q6,Q1 | SOT-23-3 | 3 | 2 | 6
 | FDD6637 | Q5,Q7,Q2,Q3 | TO-252 | 4
IC
 | 78M05D | U1 | TO-252 | 1 | 10 | 10
 | LM1117-3.3 | U2 | LM1117-3.3 | 1 | 10 | 10
 | STM32F401RCT6 | U3 | LQFP-64 | 1 | 100 | 100
 | AD823ARZ | U4 | SOIC-8 | 1 | 60 | 60
 | ACS712-20A | U5 | SOIC-8 | 1 | 100 | 100
 | AT24C32 | U6 | SOIC-8 | 1 | 20 | 20
Connectors
 | 1.27_1x6 | DEBUG | HEADER-MALE-1.27_1X6 | 1 | 15 | 15
 | BX-PH2.0-3PWZ-Y | EXT_SENSOR | CONN-TH_BX-PH2.0-3PWZ-Y | 1 | 6 | 6
 | XH2.54-4AW | CONTROL | CONN-TH_XH2.54-4AW | 1 | 5 | 5
 | KF301-5.0-2P | FAN | CONN-TH_P5.00_KF301-5.0-2P | 1 | 8 | 8
 | KF2EDGRC-5.08-5P | HOTAIR,IRON | CONN-TH_5P-P5.08_KF2EDGRC-5.08-5P | 2 | 62 | 124
 | KF2EDGRC-5.08-2P | POWER | CONN-TH_P5.08_KF2EDGRC-5.08-2P | 1 | 62 | 62
Buttons
 | B1 | RST | SWITCH SMD 4X3MM 4PIN 700955694179 | 1 | 5 | 5
 | TS-1273SY | K_1,K_2,K_3,K_4 | KEY-SMD_4P-L12.0-W12.0-P5.00-LS15.2-1 | 4 | 5 | 20
 | EN11 | EN1,EN2 | SW-TH_PEC11R-4XXXF-SXXXX | 2 | 60 | 120
Modules
 | TFT | TFT | TFT 1.77' | 1 | 200 | 200
 |  |  |  |  |  | 1251

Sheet: BOM_Soldering_station_p2
 |  |  |  | Кол-во | Цена | Итоговая цена
Capacitors
 | 10nF | C101 | TH L16.0-W5.5-P15.00-D1.2 | 1 | 10 | 10
Resistors
 | 220Ω | R101 | R0805 | 1 | 1 | 1
 | 510Ω | R107,R111 | R0805 | 2 | 1 | 2
 | 5.1kΩ | R108,R109,R112,R113 | R0805 | 4 | 1 | 4
 | 10kΩ | R102,R106,R110 | R0805 | 3 | 1 | 3
 | 39Ω | R105 | TH resistor 0.25W | 1 | 5 | 5
 | 360Ω | R103,R104 | TH resistor 0.25W | 2 | 5 | 10
 | 22Ω | R101 | TH resistor 1W | 1 | 10 | 10
Fuses
 | SMD 1206 0.5A | F1 | SMD 1206 | 1 | 8 | 8
Diodes
 | SS56 | D1,D2,D3 | SMA | 3 | 8 | 24
Transistors
 | SI2309A | Q2,Q3 | SOT-23-3 | 2 | 2 | 4
 | BTA12-600 | Q1 | TO-220 | 1
IC
 | MOC3063SR2M | U1 | SOP-6 | 1 | 20 | 20
 | PC817S | U2,U3 | SMD-4 | 2 | 10 | 20
Connectors
 | XH2.54-2AW | FAN | CONN-TH_XH2.54-4AW | 1 | 5 | 5
 | XH2.54-4AW | CONTROL | CONN-TH_XH2.54-4AW | 1 | 5 | 5
 | KF301-5.0-2P | BUTTON,INPUT,POWER_SUPPLY | CONN-TH_P5.00_KF301-5.0-2P | 3 | 8 | 24
 | KF2EDGRC-5.08-2P | POWER_1,POWER_2 | CONN-TH_5P-P5.08_KF2EDGRC-5.08-5P | 2 | 62 | 124
 | KF2EDGRC-5.08-3P | SMD | CONN-TH_P5.08_KF2EDGRC-5.08-2P | 1 | 62 | 62
Relays
 | SRD-DC24V-SL-C | K1,K2,K3 |  | 3 | 25 | 75
 |  |  |  |  |  | 416

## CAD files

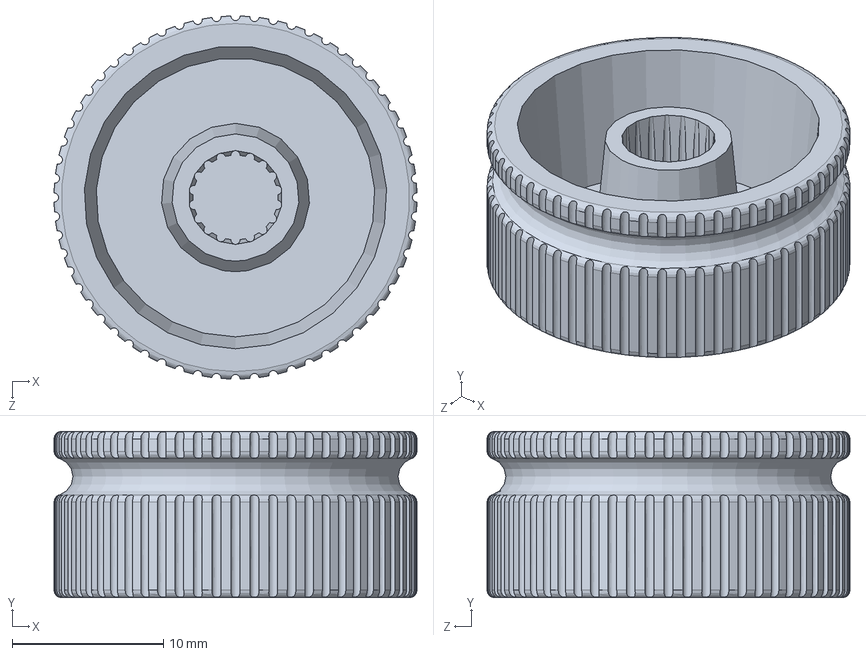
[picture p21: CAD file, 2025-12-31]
case/knob_r3.SLDPRT
24.0 x 11.0 x 24.0 mm

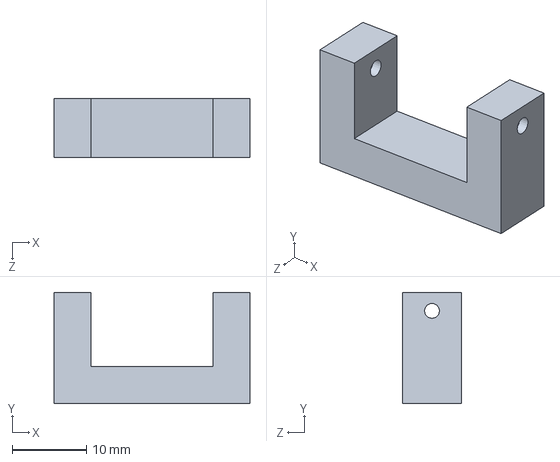
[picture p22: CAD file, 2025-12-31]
case/photocoupler.SLDPRT
26.4 x 15.0 x 8.00 mm

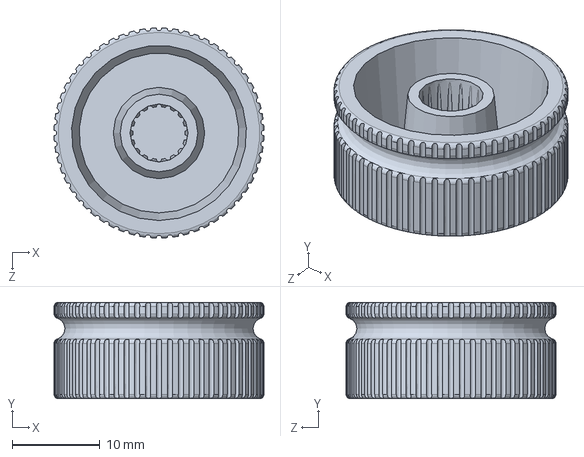
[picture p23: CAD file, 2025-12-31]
case/knob_r2.SLDPRT
24.0 x 11.0 x 24.0 mm

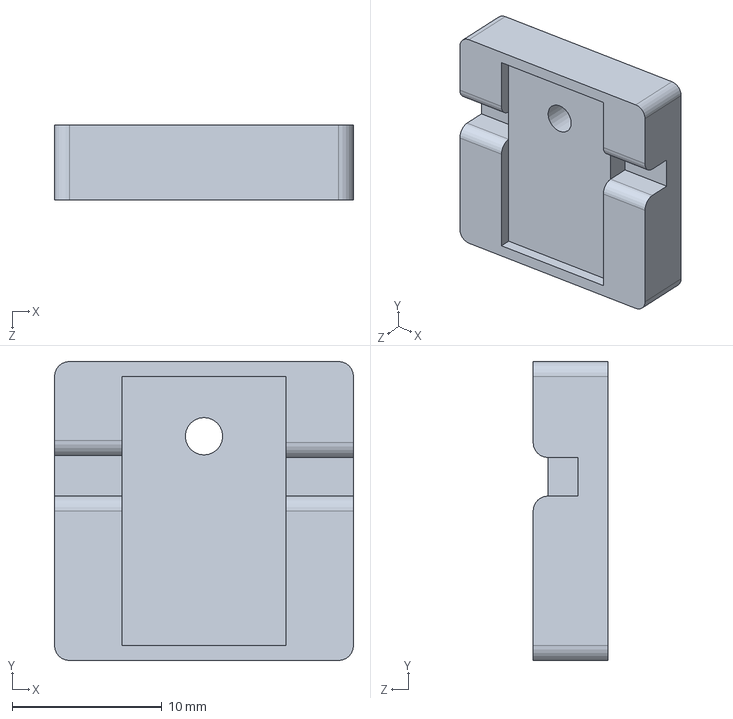
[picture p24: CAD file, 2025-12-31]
case/TO-220_PAD.SLDPRT
20.0 x 20.0 x 5.00 mm

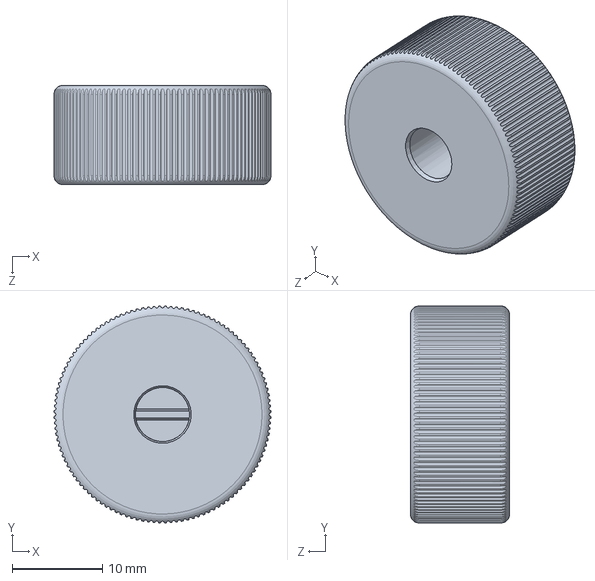
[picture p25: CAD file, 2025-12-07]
case/knob.SLDPRT
24.0 x 24.0 x 11.0 mm

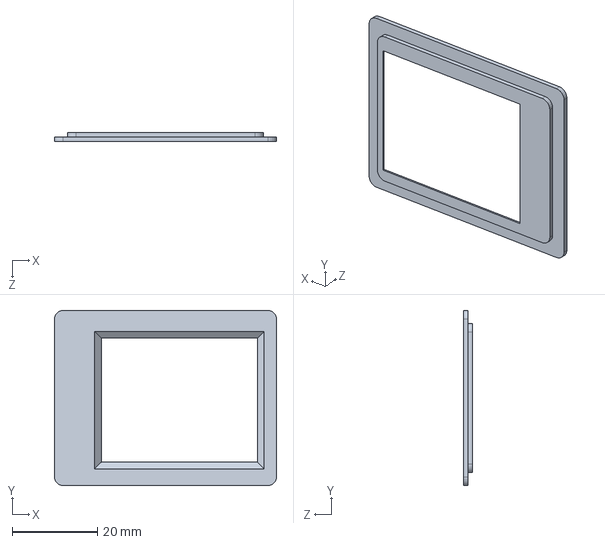
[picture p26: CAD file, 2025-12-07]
case/display_frame.SLDPRT
52.0 x 41.0 x 2.00 mm

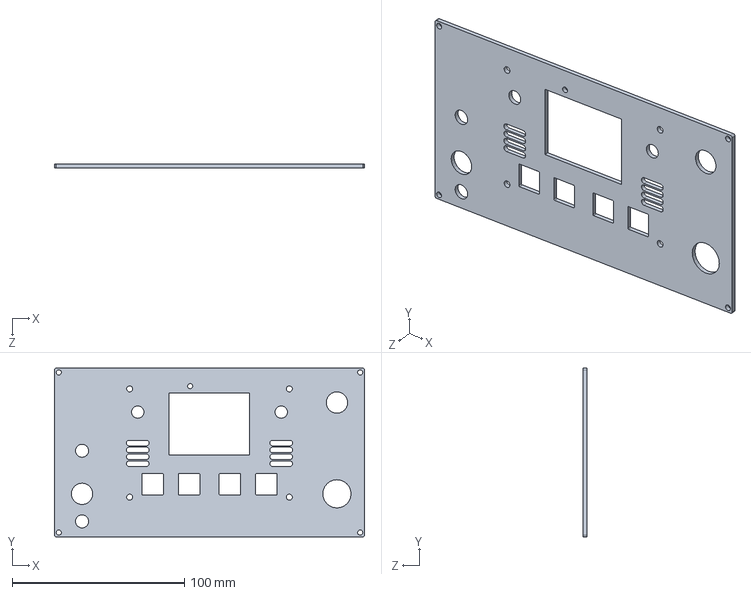
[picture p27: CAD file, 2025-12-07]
case/part_1_for_milling.SLDPRT
180.0 x 98.0 x 2.20 mm

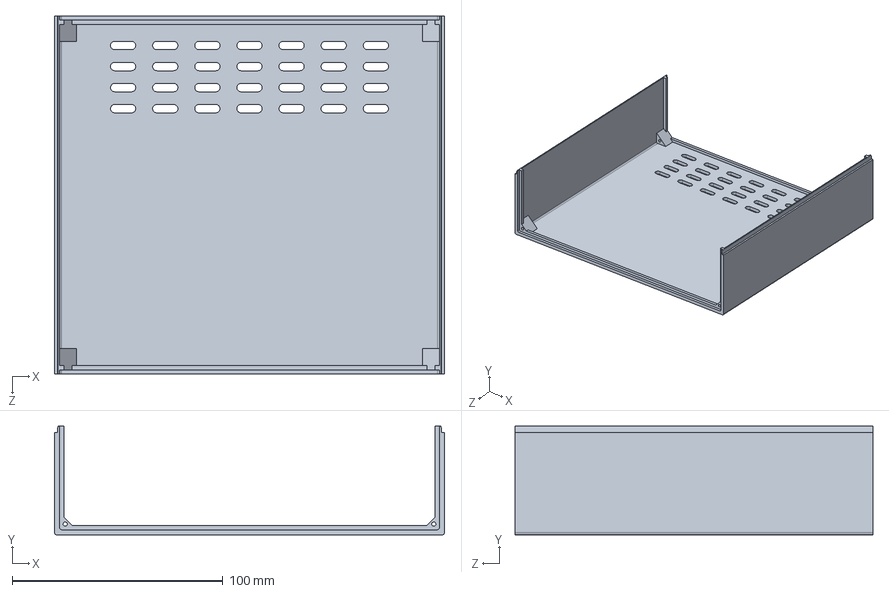
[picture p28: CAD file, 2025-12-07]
case/part_4.SLDPRT
185.2 x 51.6 x 170.0 mm

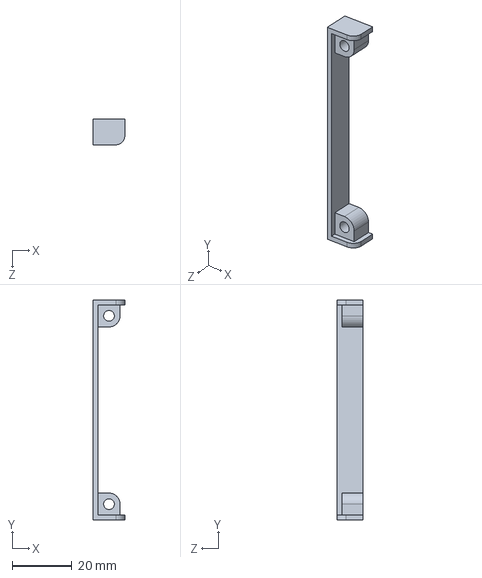
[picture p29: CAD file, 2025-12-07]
case/plate_mount.SLDPRT
10.6 x 73.5 x 8.60 mm

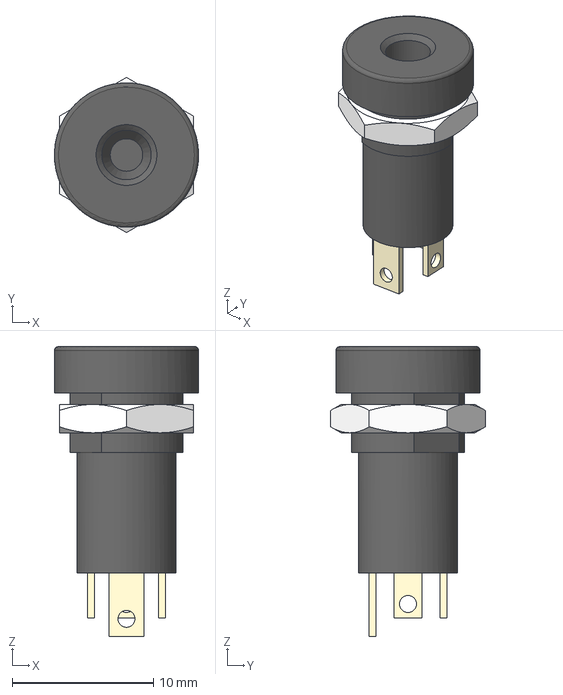
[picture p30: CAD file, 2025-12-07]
case/PJ-390A.stp
10.2 x 11.0 x 20.5 mm

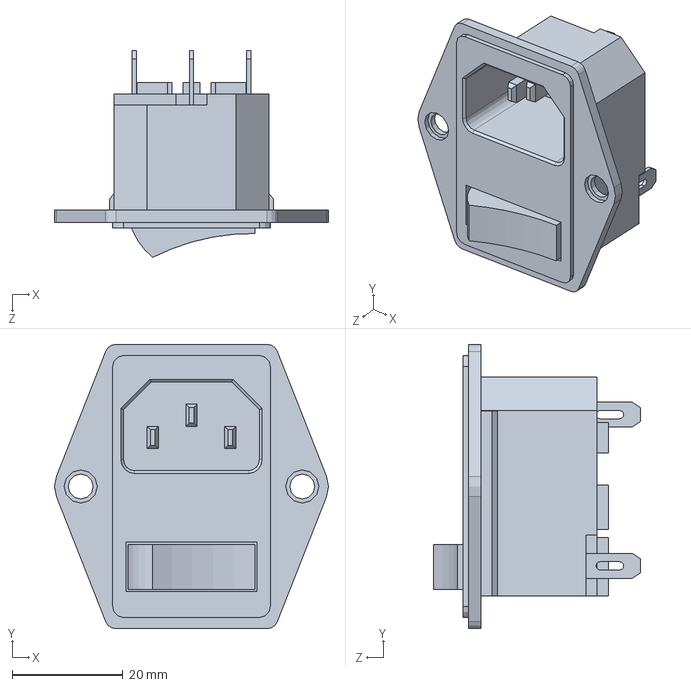
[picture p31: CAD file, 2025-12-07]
case/AC-14-F18.SLDPRT
49.5 x 51.3 x 37.3 mm

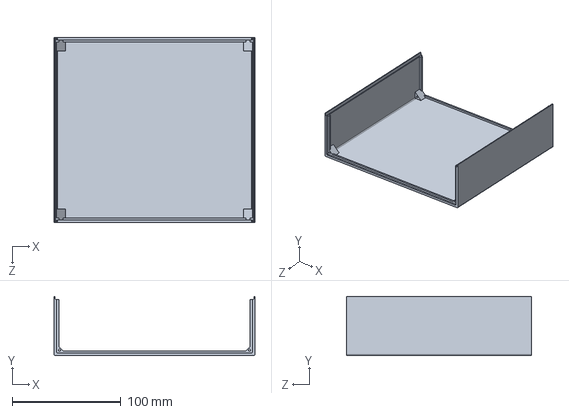
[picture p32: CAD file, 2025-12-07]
case/part_3.SLDPRT
185.2 x 54.6 x 170.0 mm

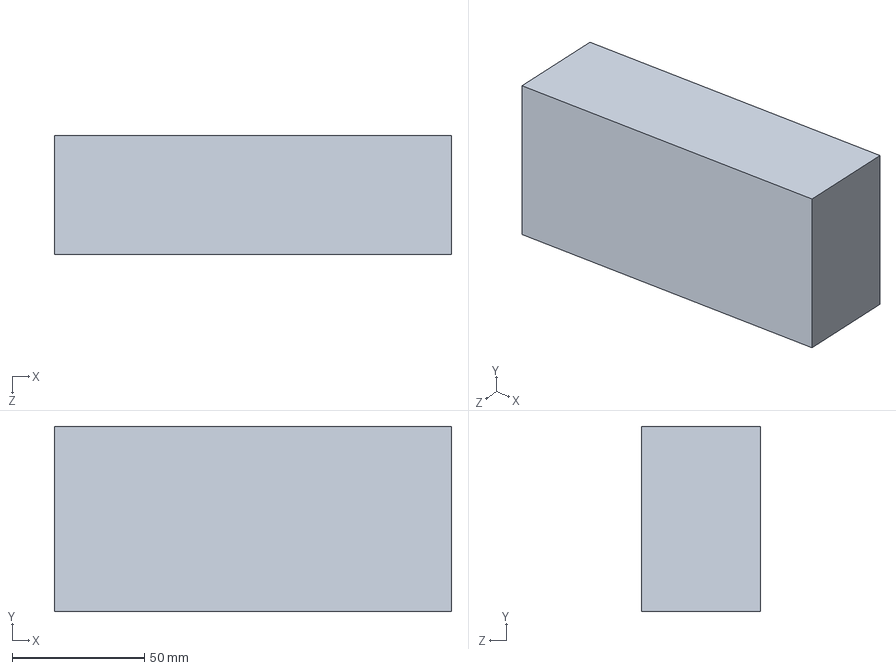
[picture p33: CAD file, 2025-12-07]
case/power_supply.SLDPRT
150.0 x 70.0 x 45.0 mm

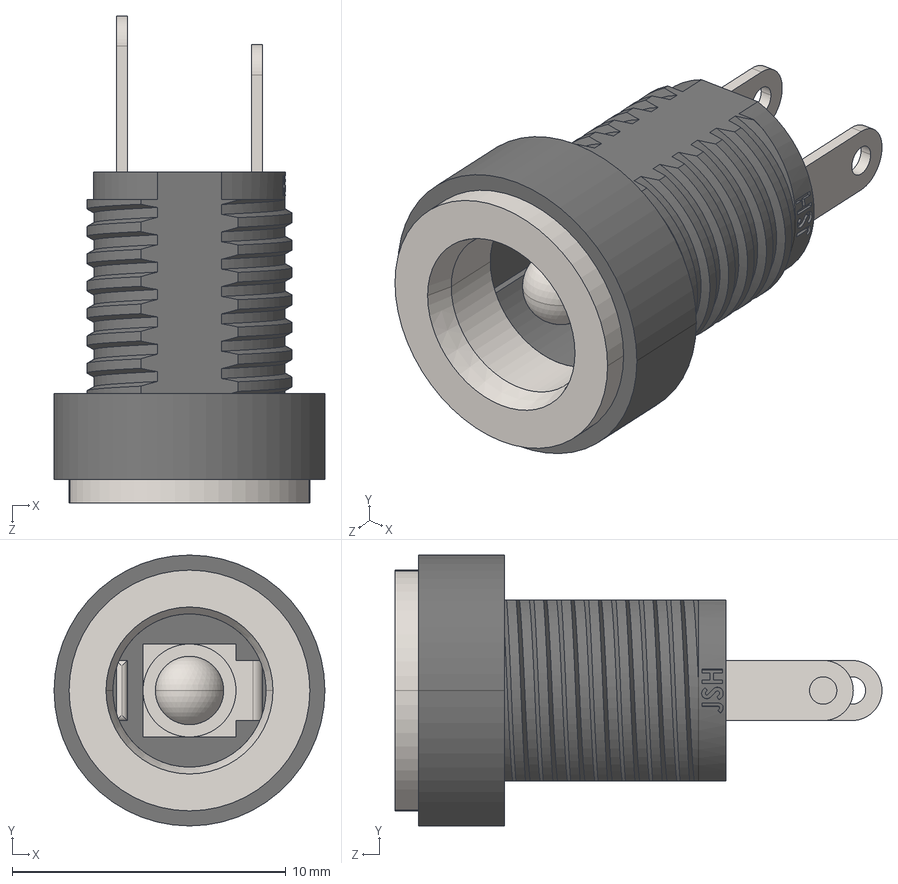
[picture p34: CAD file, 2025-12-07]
case/Jack_2.5_ST.STEP
9.90 x 9.90 x 17.8 mm

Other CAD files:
case/part_1.SLDPRT
case/gx16-8.SLDPRT
case/shim_8_3.2_1.4.SLDPRT
case/PC cooling fan.STEP
case/GX12-5 Jack.step
case/Jack_2.5_ST.IGS
case/frame.SLDPRT
case/frame.STL
case/nut_8_0.75.SLDPRT
case/part_1.STL
case/part_2.SLDPRT
case/part_2.STL
case/part_3.3mf
case/part_3.STL
case/part_4.STL
case/plate_mount.STL
case/power_supply_mount.SLDPRT
case/power_supply_mount.STL
case/shim_8_3.2_1.4.STL
case/washer_M8_14_1.SLDPRT

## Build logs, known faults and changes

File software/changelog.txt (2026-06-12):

260612
Заменена библиотека Buttons на более производительный и стабильный вариант.
Исправлены предупреждения компилятора при неявных преобразованиях указателей.

260412
Обновлена библиотека RingBuffer с улучшением производительности

260222
Обновлена библиотека ADCconverter с улучшением производительности

260131
Добавлена проверка остывания инструментов перед выключением через кнопку OFF.
Добавлен гистерезис для режима охлаждения фена.
Добавлен режим преднагрева для фена.

251224
Исправление ошибки подсчета температур с таблицами по-умолчанию.
Исправлен алгоритм установки флагов для слишком коротких импульсов ШИМ при измерении тока нагревателя паяльника.
Вынесение подсчета максимальной температуры калибровочных таблиц АЦП из ран-тайма.
Изменено значение Input Filter для таймеров, обслуживающих энкодеры.

251217
Исплавление ошибки с уходом станции в защиту при смене жала.
Доработка режимов сна / выключения и пробуждения из них.
Вынос весовых коэффициентов PID отдельно для паяльника и для термофена.

251113
Первая релизная версия.

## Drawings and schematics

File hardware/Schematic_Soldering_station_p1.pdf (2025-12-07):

## POWER

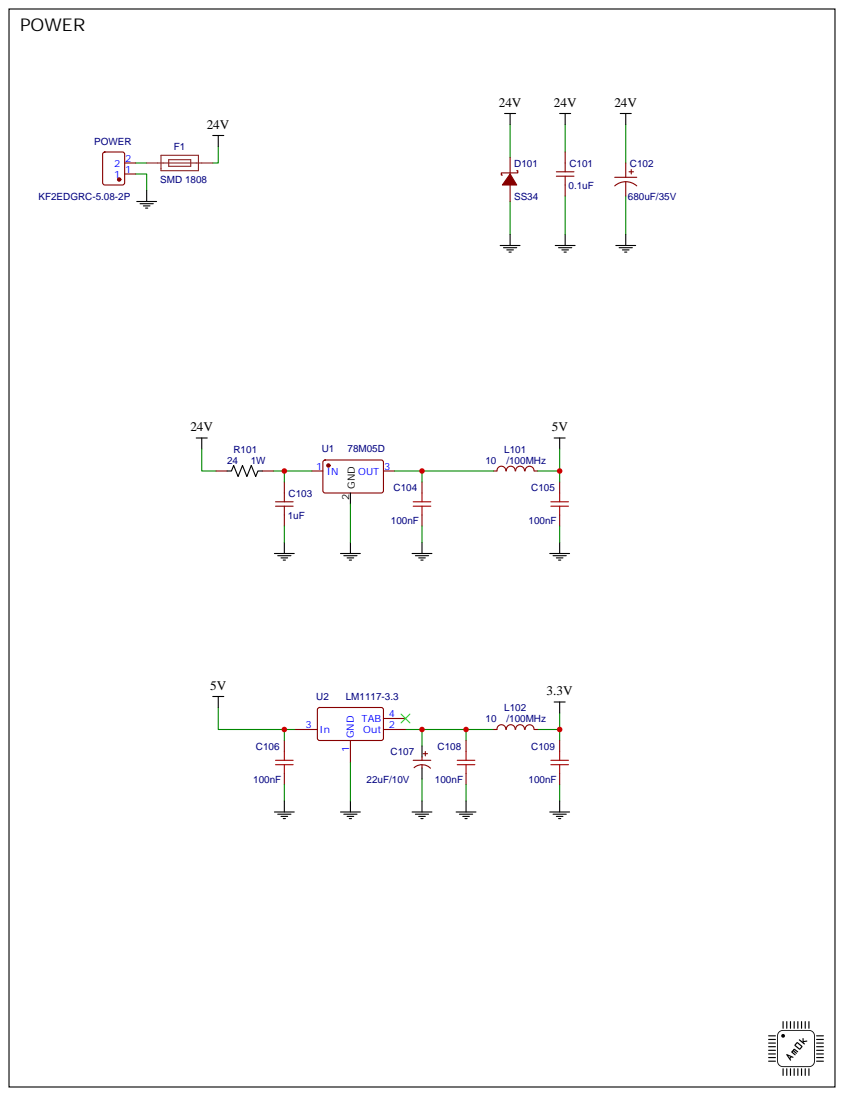
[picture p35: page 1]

## MCU

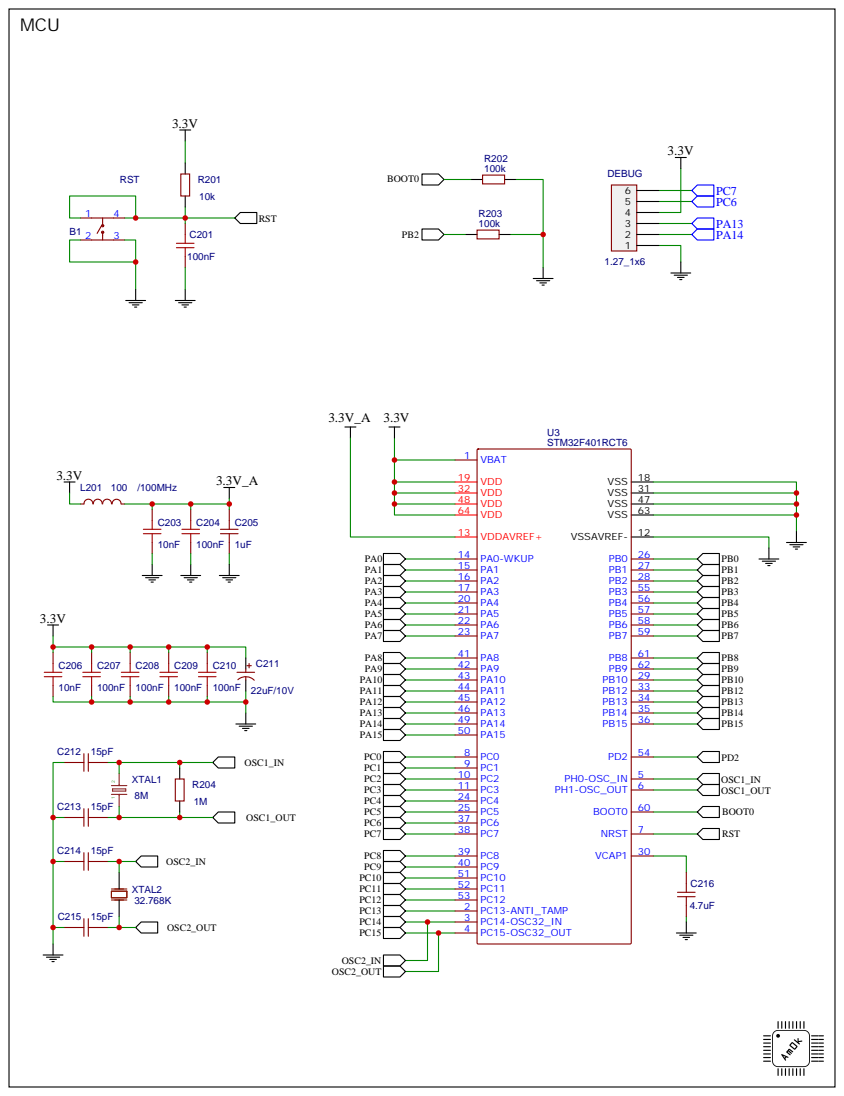
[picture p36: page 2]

## ADC

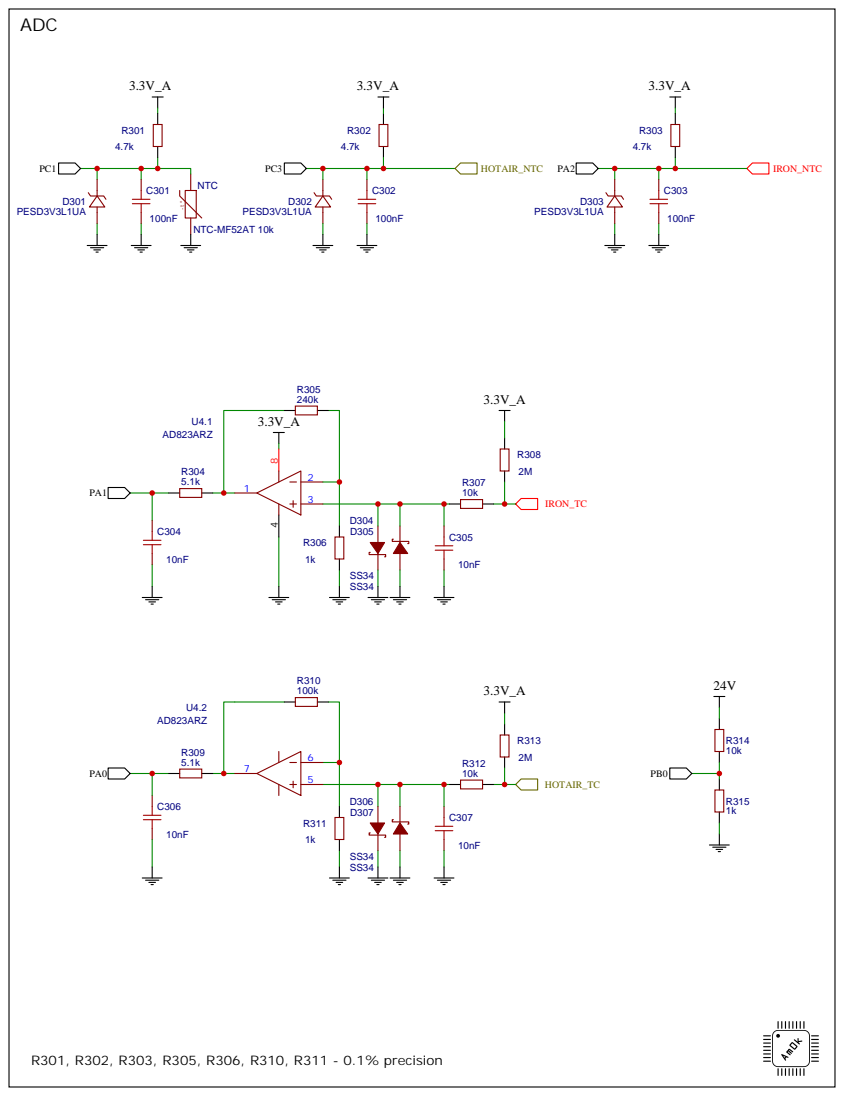
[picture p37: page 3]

## DRIVERS

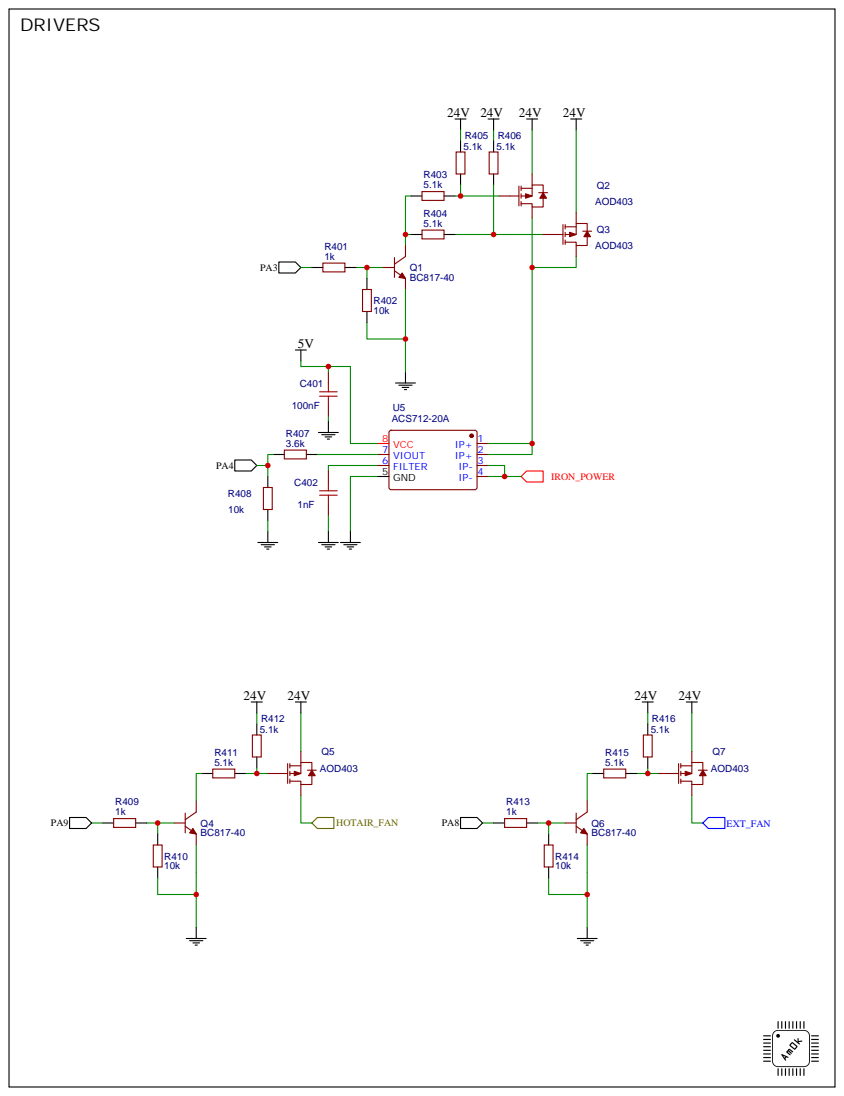
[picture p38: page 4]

## INTERFACE

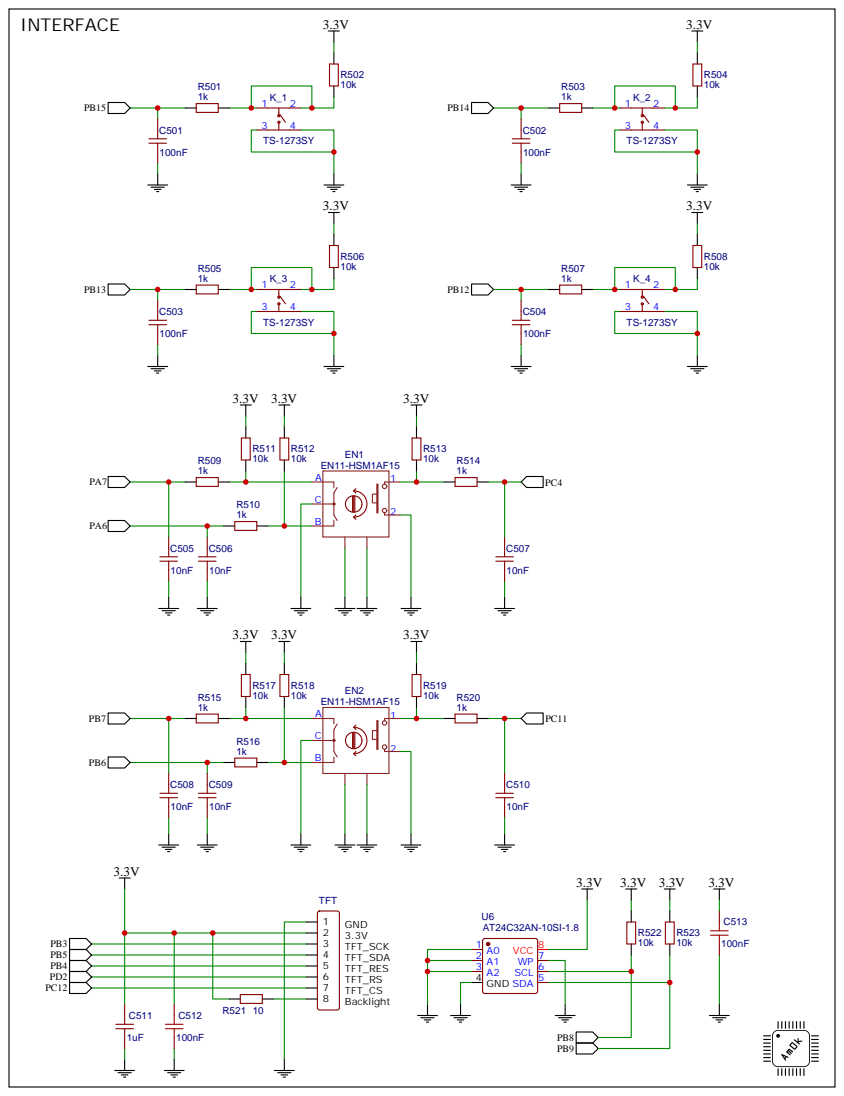
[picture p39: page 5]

HOTAIR_TC

HOTAIR_FAN
HOTAIR_NTC

IRON_TC
IRON_NTC
IRON_POWER
IRON_SENSOR

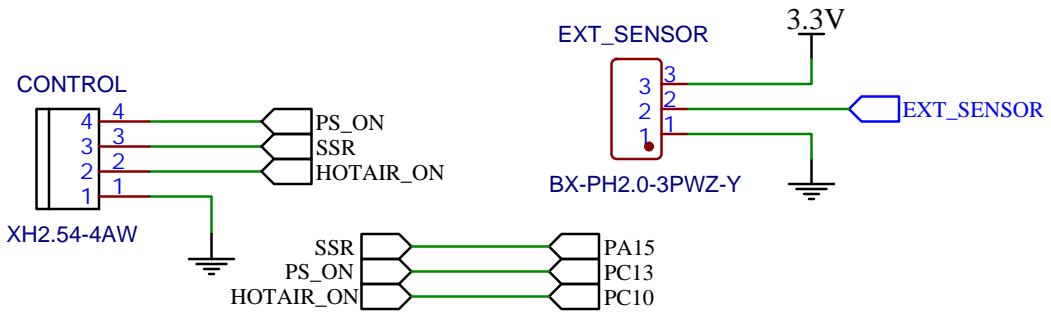
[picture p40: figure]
EXT_SENSOR; PS_ON SSR HOTAIR_ON; CONTROL; PS_ON HOTAIR_ON; SSR; BX-PH2.0-3PWZ-Y

PC5 | IRON_SENSOR

R601 1k

10k

R602

100nF

C601

3.3V | 3.3V

100nF

C602

10k

R604
R603 1k
PC0

EXT_FAN

EXT_SENSOR

KF2EDGRC-5.08-5P

IRON

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
KF2EDGRC-5.08-5P

HOTAIR

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
## OUTPUTS

## HANDLES

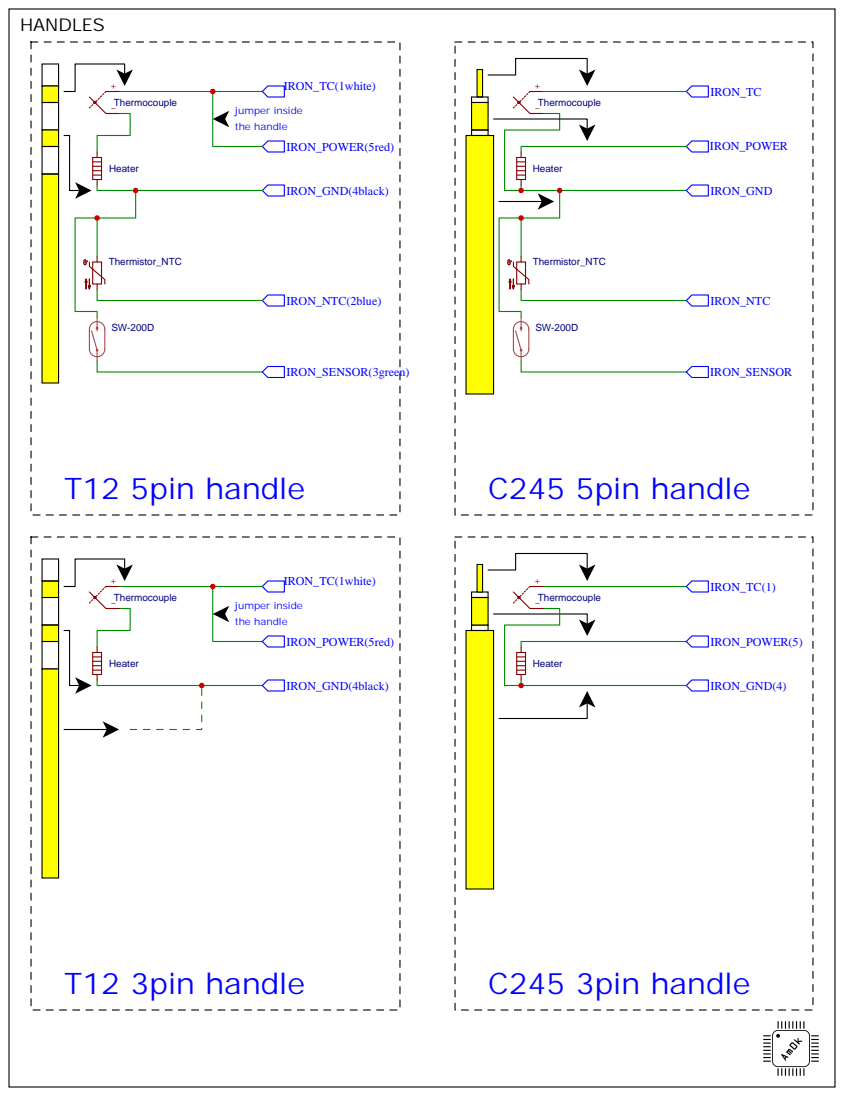
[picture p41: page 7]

## HANDLES

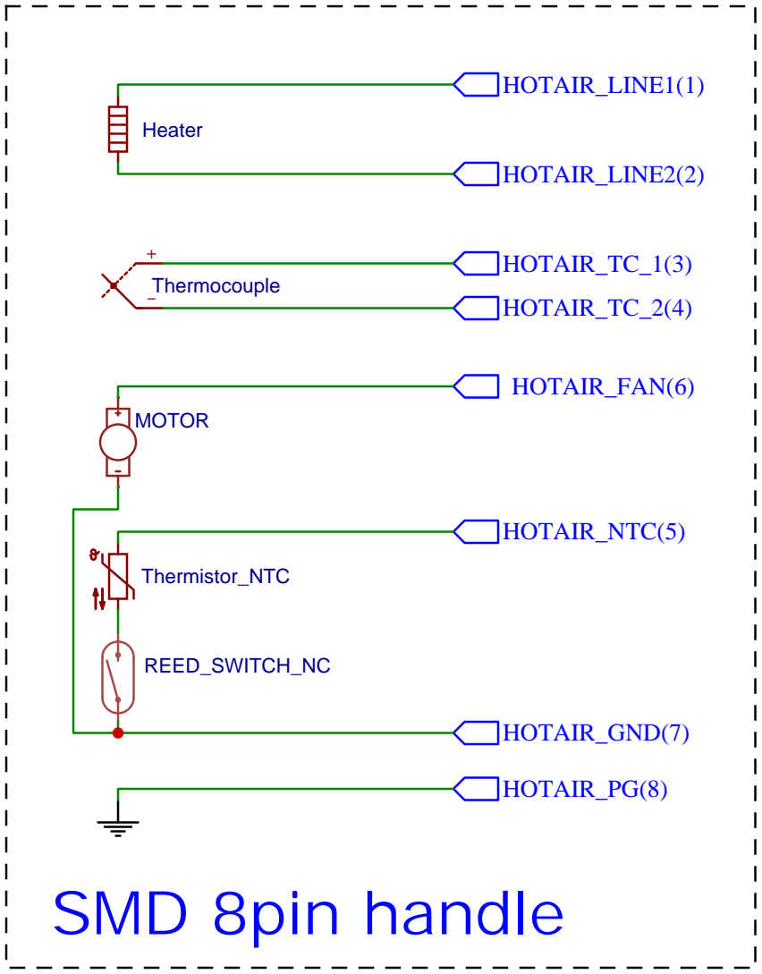
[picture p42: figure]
Heater; Thermocouple; MOTOR; Thermistor_NTC; REED_SWITCH_NC; HOTAIR_LINE1(1); HOTAIR_LINE2(2); HOTAIR_TC_1(3); HOTAIR_TC_2(4); HOTAIR_FAN(6); HOTAIR_NTC(5); HOTAIR_GND(7); HOTAIR_PG(8) SMD 8pin handle

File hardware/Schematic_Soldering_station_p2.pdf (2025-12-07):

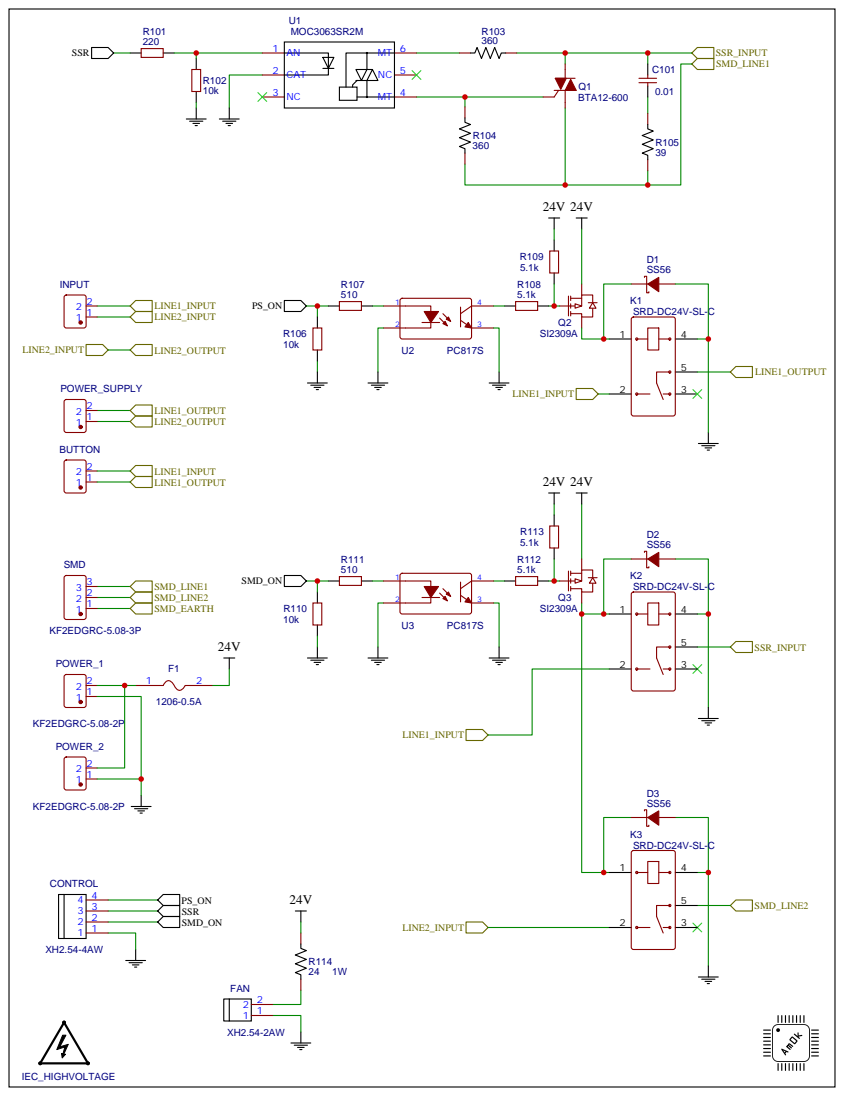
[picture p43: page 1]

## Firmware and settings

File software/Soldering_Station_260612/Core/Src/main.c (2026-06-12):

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
/* Includes ------------------------------------------------------------------*/
#include "main.h"
#include "adc.h"
#include "dma.h"
#include "i2c.h"
#include "spi.h"
#include "tim.h"
#include "usart.h"
#include "gpio.h"

/* USER CODE BEGIN Includes */

#include <stdint.h>
#include <stdbool.h>
#include <stdio.h>
#include <string.h>

#include "config.h"
#include "BUTTONS/buttons.h"
#include "24CXX/ee24.h"
#include "RingBuffer/ring_buffer.h"
#include "ADCconverter/ADCconverter.h"
#include "ADCconverter/ADCtables.h"

#include "PID/PID.h"
#include "st7735/st7735.h"
#include "st7735/fonts.h"
#include "st7735/images.h"

/* USER CODE END Includes */


/* USER CODE BEGIN PV */

volatile bool flag_changeMenu = true;                                          // menu frame update flag
volatile bool flag_IRON_on = false;                                            // soldering iron enable flag
volatile bool flag_HOTAIR_on = false;                                          // soldering gun enable flag
volatile bool flag_IRON_select_fun = false;                                    // airflow selection flag for encoder
volatile bool flag_HOTAIR_select_fun = false;                                  // airflow selection flag for encoder
volatile bool flag_IT_DMA = false;                                             // DMA interrupt triggered flag
volatile bool flag_IRON_no_tool = true;                                        // no soldering iron flag
volatile bool flag_HOTAIR_no_tool = true;                                      // no soldering gun flag

volatile bool flag_change_IRON_preset = false;                                 // flag for preset loading required
volatile bool flag_change_HOTAIR_preset = false;                               // flag for preset loading required
volatile bool flag_change_IRON_tool = true;                                    // flag for loading tool settings
volatile bool flag_change_HOTAIR_tool = true;                                   // flag for loading tool settings

static bool flag_reload_TIM3 = true;                                           // flag for the need to overwrite TIM settings for the encoder
static bool flag_reload_TIM4 = true;                                           // flag for the need to overwrite TIM settings for the encoder
volatile bool flag_TIM5_Pulse_Start = false;                                   // TIM5 pulse start flag
volatile bool flag_ADC_Start = false;                                          // ADC start flag
volatile bool flag_ADC_need_restart = false;                                   // the pulse is completed before the end of the ADC operation

volatile bool flag_OFF = false;                                                // Station need OFF flag
volatile bool flag_TIM10_Start = false;                                        // TIM10 start flag
volatile bool flag_IT_SLEEP = false;                                           // sleep mode countdown timer operation flag
volatile bool flag_IT_IRON_SENSOR = false;                                     // soldering iron handle interrupt flag
volatile bool flag_IRON_hold = false;                                          // HOLD mode
volatile bool flag_IRON_off = false;                                           // OFF mode
volatile bool flag_IRON_WAKEUP = false;                                        // need wake up IRON
volatile bool flag_IRON_NTC = false;                                           // IRON have NTC
volatile bool flag_HOTAIR_hold = false;                                        // HOLD mode
volatile bool flag_HOTAIR_off = false;                                         // OFF MODE
volatile bool flag_HOTAIR_WAKEUP = false;                                      // need wake up HOTAIR
volatile bool flag_HOTAIR_NTC = false;                                         // HOTAIR have NTC
volatile bool IRON_ext_sensor = false;
volatile bool flag_update_UI = false;
volatile bool flag_IRON_preheat_start = false;
volatile bool flag_IRON_preheat = false;
volatile bool flag_HOTAIR_preheat_start = false;
volatile bool flag_HOTAIR_preheat = false;

volatile bool flag_EEPROM_IRON_SETTINGS_OK = false;
volatile bool flag_EEPROM_HOTAIR_SETTINGS_OK = false;
volatile bool flag_EEPROM_HW_SETTINGS_OK = false;
volatile bool flag_EEPROM_IRON_TOOLS_OK = false;
volatile bool flag_EEPROM_HOTAIR_TOOLS_OK = false;
volatile bool flag_EEPROM_IRON_PRESETS_OK = false;
volatile bool flag_EEPROM_HOTAIR_PRESETS_OK = false;

volatile bool flag_write_IRON_settings = false;                                // flag for the need to write data to EEPROM
volatile bool flag_write_HOTAIR_settings = false;                              // flag for the need to write data to EEPROM
volatile bool flag_write_HW_settings = false;                                  // flag for the need to write data to EEPROM
volatile bool flag_write_IRON_tools = false;                                   // flag for the need to write data to EEPROM
volatile bool flag_write_HOTAIR_tools = false;                                 // flag for the need to write data to EEPROM
volatile bool flag_write_IRON_presets = false;                                 // flag for the need to write data to EEPROM
volatile bool flag_write_HOTAIR_presets = false;                               // flag for the need to write data to EEPROM

uint16_t tim1_ARR = TIM1_COUNT_PER_SEC / TIM1_FREQ;
uint16_t tim2_ARR = TIM2_COUNT_PER_SEC / TIM2_FREQ;
uint16_t tim5_ARR = TIM5_COUNT_PER_SEC / TIM5_FREQ;
uint16_t tim10_ARR = TIM10_COUNT_PER_SEC / TIM10_FREQ;

#ifdef DEBUG_UART
char UART_TX_Buffer[64];
#endif

char TX_Buffer[64];

EE24_HandleTypeDef ee24;                                                       // EEPROM struct

uint8_t menu = 255;                                                            // menu
// 0 - loading screen
// 1 - main screen
// 2 - IRON settings && HOTAIR settings
// 3 - IRON presets
// 4 - HOTAIR presets
// 5 - TOOLS

uint8_t selected_item = 0;                                                     // selected item in any menu
uint16_t selected_sub_menu_settings = 0;
uint8_t IRON_preset_number = 0;
uint8_t HOTAIR_preset_number = 0;
uint8_t IRON_tool_number = 0;
uint16_t selected_tool = 0;
uint8_t calibration_correction = 0;

uint16_t IT_SLEEP_count_IRON = 0;
uint16_t IT_SLEEP_count_HOTAIR = 0;
uint8_t IRON_MAX_ADC_count = 0;
uint8_t HOTAIR_MAX_ADC_count = 0;

volatile uint16_t adc[ADC_CHANNELS] = { 0, 0, 0, 0, 0, 0, 0, 0 };
uint16_t adc_filtered[ADC_CHANNELS] = { 0, 0, 0, 0, 0, 0, 0, 0 };

// [0] - IRON_TC
// [1] - HOTAIR_TC
// [2] - IRON_NTC
// [3] - HOTAIR_NTC
// [4] - ONBOARD_NTC
// [5] - 24V
// [6] - VrefInt
// [7] - IRON_amperage

RING_buffer_t ADC_values[ADC_CHANNELS];

float temperature_IRON_TC = 0;
float temperature_HOTAIR_TC = 0;
float temperature_ONBOARD_NTC = 0;
float temperature_IRON_NTC = 0;
float temperature_HOTAIR_NTC = 0;
float voltage24 = 0;
float K_adc = 1;
float IRON_amperage = 0;

uint16_t IRON_set_temp = 0;
uint16_t IRON_set_temp_RR = 0;
float IRON_real_temp = 0;
uint16_t IRON_blow = 0;

uint16_t HOTAIR_set_temp = 0;
uint16_t HOTAIR_set_temp_RR = 0;
float HOTAIR_real_temp = 0;
uint16_t HOTAIR_blow = 0;

uint32_t time_stamp = 0;
uint32_t time_prev = 0;
uint32_t time_curr = 0;
uint16_t FPS = 0;

typedef struct
{
  uint16_t min_temp;
  uint16_t max_temp;
  uint16_t step_temp;
  uint16_t min_flow;
  uint16_t max_flow;
  uint16_t step_flow;
  uint16_t ext_NTC;
  uint16_t sensor;
  uint16_t sleep_timer;
} settings_t;

typedef struct
{
  uint16_t NTC;
  uint16_t ZERO_CURRENT;
  uint16_t K_CURRENT;
  uint16_t K_VOLTAGE;
  uint16_t K_INT_NTC;
  uint16_t K_IRON_NTC;
  uint16_t K_HOTAIR_NTC;
  uint16_t time_off;
  uint16_t overcurrent_protection;
} hw_settings_t;

typedef struct
{
  uint16_t temp;
  uint16_t flow;
} preset_t;

typedef uint16_t raw_value_t;                                                  // ADC value
typedef int16_t temp_value_t;                                                  // temperature value

typedef struct
{
  temp_value_t raw_value;
  raw_value_t temp_value;
} calibration_table_t;

typedef struct
{
  uint16_t P;
  uint16_t I;
  uint16_t D;
  calibration_table_t calibration_table[5];
} tools_t;

settings_t IRON;
settings_t HOTAIR;
hw_settings_t HW_SET;

settings_t DEF_IRON = {
DEF_IRON_MIN_TEMP,
DEF_IRON_MAX_TEMP,
DEF_IRON_STEP_TEMP,
DEF_IRON_MIN_FLOW,
DEF_IRON_MAX_FLOW,
DEF_IRON_STEP_FLOW,
DEF_IRON_EXT_NTC,
DEF_IRON_EXT_SENSOR,
DEF_IRON_SLEEP_TIMER };

settings_t DEF_HOTAIR = {
DEF_HOTAIR_MIN_TEMP,
DEF_HOTAIR_MAX_TEMP,
DEF_HOTAIR_STEP_TEMP,
DEF_HOTAIR_MIN_FLOW,
DEF_HOTAIR_MAX_FLOW,
DEF_HOTAIR_STEP_FLOW,
DEF_HOTAIR_EXT_NTC,
DEF_HOTAIR_EXT_SENSOR,
DEF_HOTAIR_SLEEP_TIMER };

hw_settings_t DEF_HW_SET = {
DEF_NTC,
DEF_ZERO_CURRENT,
DEF_K_CURRENT,
DEF_K_VOLTAGE,
DEF_K_INT_NTC,
DEF_K_IRON_NTC,
DEF_K_HOTAIR_NTC,
DEF_TIME_OFF,
DEF_OVERCURRENT_PROTECTION,
};

calibration_table_t DEF_CAL_TABLE_IRON[5] = { { DEF_IRON_TOOL_ADC0, DEF_IRON_TOOL_T0 }, { DEF_IRON_TOOL_ADC1,
DEF_IRON_TOOL_T1 }, { DEF_IRON_TOOL_ADC2, DEF_IRON_TOOL_T2 }, { DEF_IRON_TOOL_ADC3, DEF_IRON_TOOL_T3 }, {
DEF_IRON_TOOL_ADC4, DEF_IRON_TOOL_T4 }, };

calibration_table_t DEF_CAL_TABLE_HOTAIR[5] = { { DEF_HOTAIR_TOOL_ADC0, DEF_HOTAIR_TOOL_T0 }, { DEF_HOTAIR_TOOL_ADC1,
DEF_HOTAIR_TOOL_T1 }, { DEF_HOTAIR_TOOL_ADC2, DEF_HOTAIR_TOOL_T2 }, { DEF_HOTAIR_TOOL_ADC3, DEF_HOTAIR_TOOL_T3 }, { DEF_HOTAIR_TOOL_ADC4,
        DEF_HOTAIR_TOOL_T4 }, };

preset_t IRON_presets[IRON_PRESETS];
preset_t HOTAIR_presets[HOTAIR_PRESETS];

preset_t DEF_IRON_presets[IRON_PRESETS] = { { 250, 70 }, { 270, 80 }, { 320, 100 }, };

preset_t DEF_HOTAIR_presets[HOTAIR_PRESETS] = { { 150, 100 }, { 320, 60 }, { 350, 100 }, };

tools_t IRON_tools[IRON_TOOLS] = { };

tools_t HOTAIR_tools;

PID_t PID_IRON;
PID_t PID_HOTAIR;

Button_t K_1;
Button_t K_2;
Button_t K_3;
Button_t K_4;
Button_t EN_1;
Button_t EN_2;
Button_t IRON_SENSOR;

/* USER CODE END PV */

void SystemClock_Config(void);
/* USER CODE BEGIN PFP */

void TIMers_Init (void);
void TIMers_Update (void);
void PID_REG_IRON (void);
void PID_REG_HOTAIR (void);
void ADC_Work (void);
void Check_Protection (void);
void Check_Sleep (void);
void Check_Tools_Change (void);

void ST7735_Update (void);
void ST7735_prepareFrame (void);
void ST7735_prepareBotMenu_v0 (void);
void ST7735_prepareBotMenu_v1 (void);
void ST7735_prepareBotMenu_v2 (void);
void ST7735_prepareMenu_0 (void);
void ST7735_prepareMenu_1 (void);
void ST7735_prepareMenu_2 (void);
void ST7735_prepareMenu_3 (uint8_t max_presets);
void ST7735_prepareMenu_5 (void);
void ST7735_showMenu_0 (void);
void ST7735_showMenu_1 (void);
void ST7735_showMenu_2_p1 (void);
void ST7735_showMenu_2_p2 (settings_t *set);
void ST7735_showMenu_2_p3 (void);
void ST7735_showMenu_3 (preset_t *preset, uint8_t max_presets, settings_t *set);
void ST7735_showMenu_5_p1 (void);
void ST7735_showMenu_5_p2 (tools_t *tool);
void ST7735_showBar (uint16_t x, uint16_t y, uint16_t length, uint16_t width, float percent);

bool EEPROM_Init (void);
void EEPROM_Show (void);
void EEPROM_Read_All (void);
void EEPROM_Write_All (void);
void EEPROM_RESET (void);

void Button_React ();

void encoder_uploader (TIM_HandleTypeDef *htim, bool *flag, uint16_t *set, uint16_t min, uint16_t max, uint8_t step);
float get_K (uint16_t K);
uint32_t approximateT (uint16_t ADC_4, uint16_t ADC_3, uint16_t ADC_2, uint16_t T_3, uint16_t T_2);
float get_NTC_T (uint16_t table, float K, uint16_t adc);

void TEST_INFO ();

/* USER CODE END PFP */

/**
  * @brief  The application entry point.
  * @retval int
  */
int main(void)
{

  /* MCU Configuration--------------------------------------------------------*/

  /* Reset of all peripherals, Initializes the Flash interface and the Systick. */
  HAL_Init();

  /* Configure the system clock */
  SystemClock_Config();

  /* Initialize all configured peripherals */
  MX_GPIO_Init();
  MX_DMA_Init();
  MX_I2C1_Init();
  MX_ADC1_Init();
  MX_TIM1_Init();
  MX_TIM2_Init();
  MX_TIM3_Init();
  MX_TIM4_Init();
  MX_USART6_UART_Init();
  MX_TIM5_Init();
  MX_SPI1_Init();
  MX_TIM10_Init();
  MX_TIM11_Init();
  /* USER CODE BEGIN 2 */

  HAL_GPIO_WritePin (PS_ON_GPIO_Port, PS_ON_Pin, 1);
  HAL_GPIO_WritePin (SSR_ON_GPIO_Port, SSR_ON_Pin, 1);

  Button_Init (&K_1, K_1_GPIO_Port, K_1_Pin);
  Button_Init (&K_2, K_2_GPIO_Port, K_2_Pin);
  Button_Init (&K_3, K_3_GPIO_Port, K_3_Pin);
  Button_Init (&K_4, K_4_GPIO_Port, K_4_Pin);
  Button_Init (&EN_1, EN_1_GPIO_Port, EN_1_Pin);
  Button_Init (&EN_2, EN_2_GPIO_Port, EN_2_Pin);
  Button_Init (&IRON_SENSOR, IRON_SENSOR_GPIO_Port, IRON_SENSOR_Pin);

  ST7735_Init ();

  #ifdef DEBUG_UART
  snprintf (UART_TX_Buffer, 64, "Start loading Amok Soldering station.\n");
  HAL_UART_Transmit (UART_HEANDLER, (uint8_t*) UART_TX_Buffer, strlen (UART_TX_Buffer), 10);
  snprintf (UART_TX_Buffer, 64, "Firmware version: %6i .\n", VERSION);
  HAL_UART_Transmit (UART_HEANDLER, (uint8_t*) UART_TX_Buffer, strlen (UART_TX_Buffer), 10);
  #endif

  if (EEPROM_Init ())
  {
    EEPROM_Read_All ();
    menu = 0;
    #ifdef DEBUG_UART_EEPROM
    EEPROM_Show ();
    #endif
  }
  else
  {
    menu = 1;
    #ifdef DEBUG_UART_EEPROM
    snprintf (UART_TX_Buffer, 64, "Cant init EEPROM!\n");
    HAL_UART_Transmit (UART_HEANDLER, (uint8_t*) UART_TX_Buffer, strlen (UART_TX_Buffer), 10);
    #endif
  }

  TIMers_Init ();

  for (uint8_t i = 0; i < ADC_CHANNELS; i++)
  {
    RING_BUF_Init (&ADC_values[i], ADC_BUFFER_SIZE);
  }

  time_stamp = HAL_GetTick ();

  /* USER CODE END 2 */

  /* Infinite loop */
  /* USER CODE BEGIN WHILE */
  while (1)
  {
    /* USER CODE END WHILE */

    /* USER CODE BEGIN 3 */

    Button_React ();

    TIMers_Update ();

    ADC_Work ();

    ST7735_Update ();

    Check_Protection ();

    Check_Sleep ();

    Check_Tools_Change ();

    EEPROM_Write_All ();
  }
  /* USER CODE END 3 */
}

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
/* USER CODE BEGIN 4 */

// ****************** Callback по завершению работы АЦП ***********************
void HAL_ADC_ConvCpltCallback (ADC_HandleTypeDef *hadc)
{
  if (hadc->Instance == ADC1)                                                  // по завершению работы ADC
  {
    HAL_ADC_Stop_DMA (&hadc1);                                                 // останавливаем работу ADC в режиме DMA
    flag_ADC_Start = false;                                                    // сбрасываем флаг работы ADC

    if (flag_TIM5_Pulse_Start)                                                 // если ADC запущен в начале периода PWM
    {
      if (!flag_ADC_need_restart)                                              // если не произошел конец импульса до конца работы ADC
        RING_BUF_Push (&ADC_values[7], adc[7]);                                // отправляем в кольцевой буфер значение ADC[7] (ток жала)
    }
    else                                                                       // если ADC запущен по окончанию периода PWM
    {
      if (adc[0] > ADC_MAX_VALUE)                                              // проверяем подключение термопары паяльника
      {
        IRON_MAX_ADC_count++;
      }
      else                                                                     // если термопара подключена
      {
        flag_IRON_no_tool = false;
        IRON_MAX_ADC_count = 0;
        RING_BUF_Push (&ADC_values[0], adc[0]);                                // отправляем в кольцевой буфер значения ADC[0]
      }

      if (adc[1] > ADC_MAX_VALUE)                                              // проверяем подключение термопары фена
      {
        HOTAIR_MAX_ADC_count++;
      }
      else                                                                     // если термопара подключена
      {
        flag_HOTAIR_no_tool = false;
        HOTAIR_MAX_ADC_count = 0;
        RING_BUF_Push (&ADC_values[1], adc[1]);                                // отправляем в кольцевой буфер значение ADC[1]
      }

      if (adc[2] > ADC_MAX_VALUE)                                              // проверяем подключение NTC резистора в рукоятке паяльника
      {
        flag_IRON_NTC = false;
      }
      else                                                                     // если NTC резистор подключен
      {
        flag_IRON_NTC = true;
        RING_BUF_Push (&ADC_values[2], adc[2]);                                // отправляем в кольцевой буфер значение ADC[2]
      }

      if (adc[3] > ADC_MAX_VALUE)                                              // проверяем подключение NTC резистора в рукоятке фена
      {
        flag_HOTAIR_NTC = false;
      }
      else                                                                     // если NTC резистор подключен
      {
        flag_HOTAIR_NTC = true;
        RING_BUF_Push (&ADC_values[3], adc[3]);                                // отправляем в кольцевой буфер значение ADC[3]
      }

      for (uint8_t i = 4; i < ADC_CHANNELS - 1; i++)                           // для каналов ADC[4-6]
      {
        RING_BUF_Push (&ADC_values[i], adc[i]);                                // отправляем в кольцевой буфер значения ADC[4-6]
      }

      HAL_TIM_PWM_Start_IT (&htim5, TIM_CHANNEL_4);                            // запускаем PWM TIM5
      __HAL_TIM_ENABLE_IT(&htim5, TIM_IT_UPDATE);

      HAL_TIM_Base_Start_IT (&htim10);                                         // запускаем TIM10 (для получения тока жала)
      flag_TIM5_Pulse_Start = true;                                            // поднимаем флаг начала периода PWM
      flag_ADC_Start = true;                                                   // поднимаем флаг начала работы ADC
      flag_ADC_need_restart = false;                                           // сбрасываем флаг слишком короткого импульса
    }

    flag_IT_DMA = true;                                                        // поднимаем флаг окончания работы прерывания DMA
  }
}
// ****************************************************************************

// ****************** Callback по завершению положительного импульса TIM5 *****
void HAL_TIM_PWM_PulseFinishedCallback (TIM_HandleTypeDef *htim)
{
  if (htim->Instance == TIM5)                                                  // по окончанию импульса PWM TIM5
  {
    if (flag_ADC_Start)                                                        // если ADC сейчас запущено (еще не завершило работу)
    {
      flag_ADC_need_restart = true;                                            // поднимаем флаг слишком короткого импульса
    }
  }
}
// ****************************************************************************

// ****************** Callback TIM5, TIM10, TIM11 *****************************
void HAL_TIM_PeriodElapsedCallback (TIM_HandleTypeDef *htim)
{
  if (htim->Instance == TIM2)                                                  // по завершению периода TIM2
  {
    PID_REG_HOTAIR ();
  }

  if (htim->Instance == TIM5)                                                  // по завершению периода TIM5
  {
    HAL_TIM_PWM_Stop_IT (&htim5, TIM_CHANNEL_4);                               // отключаем PWM
    HAL_TIM_Base_Start_IT (&htim10);                                           // запускаем таймер задержки перед измерением
    flag_TIM5_Pulse_Start = false;
    flag_ADC_Start = true;
    PID_REG_IRON ();
  }

  if (htim->Instance == TIM10)                                                 // по завершению периода TIM10
  {
    HAL_TIM_Base_Stop_IT (&htim10);                                            // отключаем TIM10
    HAL_ADC_Start_DMA (&hadc1, (uint32_t*) &adc, ADC_CHANNELS);                // запускаем ADC в режиме DMA
  }

  if (htim->Instance == TIM11)                                                 // по завершению периода TIM11
  {
    Button_Process ();
    flag_update_UI = true;
    IRON_ext_sensor = HAL_GPIO_ReadPin (EXT_SENSOR_GPIO_Port, EXT_SENSOR_Pin); // проверяем подставку
    IT_SLEEP_count_IRON++;                                                     // увеличиваем счетчик сна для IRON
    IT_SLEEP_count_HOTAIR++;                                                   // увеличиваем счетчик сна для HOTAIR
  }
}
// ****************************************************************************

// ****************** �?нициализация таймеров *********************************
void TIMers_Init (void)
{
  // *** Air blow TIM
  TIM1->PSC = TIM1_PSC;
  TIM1->ARR = TIM1_ARR;
  TIM1->EGR |= TIM_EGR_UG;

  // *** HOTAIR PWM TIM
  TIM2->PSC = TIM2_PSC;
  TIM2->ARR = TIM2_ARR;
  TIM2->EGR |= TIM_EGR_UG;

  // *** IRON PWM TIM
  TIM5->PSC = TIM5_PSC;
  TIM5->ARR = TIM5_ARR;
  TIM5->EGR |= TIM_EGR_UG;

  // *** MEASUREMENT DELAY TIM
  TIM10->PSC = TIM10_PSC;
  TIM10->ARR = MEASUREMENT_DELAY;
  TIM10->EGR |= TIM_EGR_UG;

  // *** SLEEP COUNT INCREASE TASK
  TIM11->PSC = TIM11_PSC;
  TIM11->ARR = TIM11_ARR;

  TIM1->CCR1 = 0;
  TIM1->CCR2 = 0;

  TIM2->CCR1 = 0;

  TIM5->CCR4 = 0;

  HAL_TIM_PWM_Start (&htim1, TIM_CHANNEL_1);
  HAL_TIM_PWM_Start (&htim1, TIM_CHANNEL_2);

  //HAL_TIM_PWM_Start (&htim2, TIM_CHANNEL_1);
  HAL_TIM_PWM_Start_IT (&htim2, TIM_CHANNEL_1);                                // Запускаем PWM TIM5
  __HAL_TIM_ENABLE_IT(&htim2, TIM_IT_UPDATE);

  HAL_TIM_Encoder_Start (&htim3, TIM_CHANNEL_1);
  HAL_TIM_Encoder_Start (&htim4, TIM_CHANNEL_1);

  HAL_TIM_PWM_Start_IT (&htim5, TIM_CHANNEL_4);                                // Запускаем PWM TIM5
  __HAL_TIM_ENABLE_IT(&htim5, TIM_IT_UPDATE);

  PID_Init (&PID_IRON, false);
  PID_SetLimits (&PID_IRON, 0, TIM5->ARR);
  PID_SetSync (&PID_IRON, round(1000 / TIM5_FREQ) + 1);

  PID_Init (&PID_HOTAIR, false);
  PID_SetLimits (&PID_HOTAIR, 0, TIM2->ARR);
  PID_SetSync (&PID_HOTAIR, round(1000 / TIM2_FREQ) + 1);

  HAL_TIM_Base_Start_IT (&htim11);                                             // прерывания TIM11
}
// ****************************************************************************
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

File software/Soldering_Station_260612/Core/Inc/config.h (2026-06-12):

/***********************************************************************************************************

  Author:     Am0k
  Github:     https://github.com/Am0k-GIT

***********************************************************************************************************/

#ifndef INC_CONFIG_H_
#define INC_CONFIG_H_

//#define DEBUG_UART
//#define DEBUG_UART_PID
//#define DEBUG_UART_EEPROM
//#define DEBUG_UART_UI
#define UART_HEANDLER                            &huart6

#define VERSION                                  260612

#define DEF_IRON_MIN_TEMP                        150
#define DEF_IRON_MAX_TEMP                        450
#define DEF_IRON_STEP_TEMP                       10
#define DEF_IRON_MIN_FLOW                        50
#define DEF_IRON_MAX_FLOW                        100
#define DEF_IRON_STEP_FLOW                       10
#define DEF_IRON_EXT_NTC                         0
#define DEF_IRON_EXT_SENSOR                      0
#define DEF_IRON_SLEEP_TIMER                     120

#define DEF_HOTAIR_MIN_TEMP                      120
#define DEF_HOTAIR_MAX_TEMP                      450
#define DEF_HOTAIR_STEP_TEMP                     10
#define DEF_HOTAIR_MIN_FLOW                      40
#define DEF_HOTAIR_MAX_FLOW                      100
#define DEF_HOTAIR_STEP_FLOW                     10
#define DEF_HOTAIR_EXT_NTC                       0
#define DEF_HOTAIR_EXT_SENSOR                    0
#define DEF_HOTAIR_SLEEP_TIMER                   60

#define DEF_NTC                                  1
#define DEF_ZERO_CURRENT                         2281
#define DEF_K_CURRENT                            100
#define DEF_K_VOLTAGE                            100
#define DEF_K_INT_NTC                            100
#define DEF_K_IRON_NTC                           100
#define DEF_K_HOTAIR_NTC                         100
#define DEF_TIME_OFF                             20*60                         // S
#define DEF_OVERCURRENT_PROTECTION               9                             // A

#define DEF_IRON_TOOL_P                          200
#define DEF_IRON_TOOL_I                          200
#define DEF_IRON_TOOL_D                          200
#define DEF_IRON_TOOL_ADC0                       80                            // T12: 0062 C245: 0080
#define DEF_IRON_TOOL_ADC1                       600                           // T12: 0380 C245: 0600
#define DEF_IRON_TOOL_ADC2                       1330                          // T12: 0850 C245: 1330
#define DEF_IRON_TOOL_ADC3                       2040                          // T12: 1425 C245: 2040
#define DEF_IRON_TOOL_ADC4                       4000                          // T12: 1425 C245: 2720
#define DEF_IRON_TOOL_T0                         0
#define DEF_IRON_TOOL_T1                         120
#define DEF_IRON_TOOL_T2                         240
#define DEF_IRON_TOOL_T3                         360
#define DEF_IRON_TOOL_T4                         (DEF_IRON_TOOL_ADC4 - DEF_IRON_TOOL_ADC3)*(DEF_IRON_TOOL_T3 - DEF_IRON_TOOL_T2)/(DEF_IRON_TOOL_ADC3 - DEF_IRON_TOOL_ADC2) + DEF_IRON_TOOL_T3

#define DEF_HOTAIR_TOOL_P                        200
#define DEF_HOTAIR_TOOL_I                        200
#define DEF_HOTAIR_TOOL_D                        200
#define DEF_HOTAIR_TOOL_ADC0                     80
#define DEF_HOTAIR_TOOL_ADC1                     640
#define DEF_HOTAIR_TOOL_ADC2                     1315
#define DEF_HOTAIR_TOOL_ADC3                     1935
#define DEF_HOTAIR_TOOL_ADC4                     4000
#define DEF_HOTAIR_TOOL_T0                       0
#define DEF_HOTAIR_TOOL_T1                       120
#define DEF_HOTAIR_TOOL_T2                       240
#define DEF_HOTAIR_TOOL_T3                       360
#define DEF_HOTAIR_TOOL_T4                       (DEF_HOTAIR_TOOL_ADC4 - DEF_HOTAIR_TOOL_ADC3)*(DEF_HOTAIR_TOOL_T3 - DEF_HOTAIR_TOOL_T2)/(DEF_HOTAIR_TOOL_ADC3 - DEF_HOTAIR_TOOL_ADC2) + DEF_HOTAIR_TOOL_T3

#define LIM_MIN_TEMP                             100
#define LIM_MAX_TEMP                             500
#define LIM_MIN_STEP_TEMP                        1
#define LIM_MAX_STEP_TEMP                        20
#define LIM_MIN_FAN                              10
#define LIM_MAX_FAN                              100
#define LIM_MIN_STEP_FAN                         1
#define LIM_MAX_STEP_FAN                         25
#define LIM_MIN_SLEEP_TIMER                      0
#define LIM_MAX_SLEEP_TIMER                      600
#define LIM_STEP_SLEEP_TIMER                     10
#define LIM_MIN_PID_K                            0
#define LIM_MAX_PID_K                            1000
#define LIM_STEP_PID_K                           1
#define LIM_MIN_ADC                              0
#define LIM_MAX_ADC                              4095
#define LIM_STEP_ADC                             1
#define LIM_CALIBRATION_RANGEWIDTH               60

#define LOADING_SCREEN_TIME                      3000                          // mS
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

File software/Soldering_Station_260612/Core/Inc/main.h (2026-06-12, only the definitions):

#define PS_ON_Pin GPIO_PIN_13
#define PS_ON_GPIO_Port GPIOC
#define EXT_SENSOR_Pin GPIO_PIN_0
#define EXT_SENSOR_GPIO_Port GPIOC
#define ONBOARD_NTC_Pin GPIO_PIN_1
#define ONBOARD_NTC_GPIO_Port GPIOC
#define HOTAIR_NTC_Pin GPIO_PIN_3
#define HOTAIR_NTC_GPIO_Port GPIOC
#define HOTAIR_TC_Pin GPIO_PIN_0
#define HOTAIR_TC_GPIO_Port GPIOA
#define IRON_TC_Pin GPIO_PIN_1
#define IRON_TC_GPIO_Port GPIOA
#define IRON_NTC_Pin GPIO_PIN_2
#define IRON_NTC_GPIO_Port GPIOA
#define IRON_OUTPUT_Pin GPIO_PIN_3
#define IRON_OUTPUT_GPIO_Port GPIOA
#define IRON_POWER_Pin GPIO_PIN_4
#define IRON_POWER_GPIO_Port GPIOA
#define EN1_B_Pin GPIO_PIN_6
#define EN1_B_GPIO_Port GPIOA
#define EN1_A_Pin GPIO_PIN_7
#define EN1_A_GPIO_Port GPIOA
#define EN_1_Pin GPIO_PIN_4
#define EN_1_GPIO_Port GPIOC
#define EN_1_EXTI_IRQn EXTI4_IRQn
#define IRON_SENSOR_Pin GPIO_PIN_5
#define IRON_SENSOR_GPIO_Port GPIOC
#define IRON_SENSOR_EXTI_IRQn EXTI9_5_IRQn
#define VOLTAGE_24V_Pin GPIO_PIN_0
#define VOLTAGE_24V_GPIO_Port GPIOB
#define K_4_Pin GPIO_PIN_12
#define K_4_GPIO_Port GPIOB
#define K_4_EXTI_IRQn EXTI15_10_IRQn
#define K_3_Pin GPIO_PIN_13
#define K_3_GPIO_Port GPIOB
#define K_3_EXTI_IRQn EXTI15_10_IRQn
#define K_2_Pin GPIO_PIN_14
#define K_2_GPIO_Port GPIOB
#define K_2_EXTI_IRQn EXTI15_10_IRQn
#define K_1_Pin GPIO_PIN_15
#define K_1_GPIO_Port GPIOB
#define K_1_EXTI_IRQn EXTI15_10_IRQn
#define EXT_FAN_Pin GPIO_PIN_8
#define EXT_FAN_GPIO_Port GPIOA
#define HOTAIR_FAN_Pin GPIO_PIN_9
#define HOTAIR_FAN_GPIO_Port GPIOA
#define SSR_ON_Pin GPIO_PIN_10
#define SSR_ON_GPIO_Port GPIOC
#define EN_2_Pin GPIO_PIN_11
#define EN_2_GPIO_Port GPIOC
#define EN_2_EXTI_IRQn EXTI15_10_IRQn
#define TFT_CS_Pin GPIO_PIN_12
#define TFT_CS_GPIO_Port GPIOC
#define TFT_RS_Pin GPIO_PIN_2
#define TFT_RS_GPIO_Port GPIOD
#define TFT_SCK_Pin GPIO_PIN_3
#define TFT_SCK_GPIO_Port GPIOB
#define TFT_RES_Pin GPIO_PIN_4
#define TFT_RES_GPIO_Port GPIOB
#define TFT_SDA_Pin GPIO_PIN_5
#define TFT_SDA_GPIO_Port GPIOB
#define EN2_B_Pin GPIO_PIN_6
#define EN2_B_GPIO_Port GPIOB
#define EN2_A_Pin GPIO_PIN_7
#define EN2_A_GPIO_Port GPIOB

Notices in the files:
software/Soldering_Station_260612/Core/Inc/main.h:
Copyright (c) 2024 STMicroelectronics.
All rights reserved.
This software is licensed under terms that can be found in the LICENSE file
